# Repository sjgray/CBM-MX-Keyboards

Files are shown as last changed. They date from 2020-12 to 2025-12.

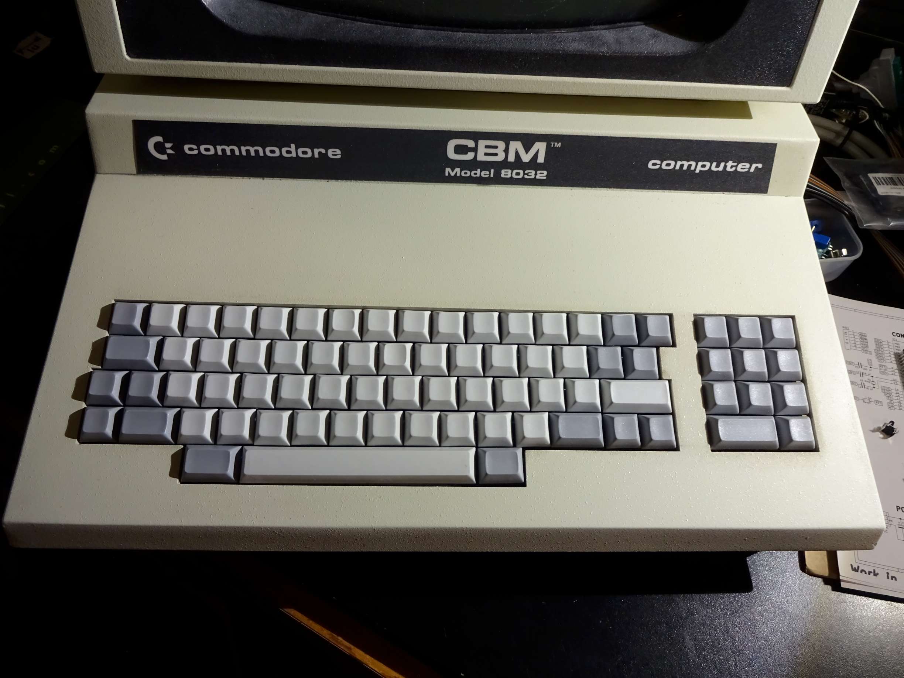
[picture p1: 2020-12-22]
PET-B/B-V1-R1/_Pics/b-v1-r1-installed.jpg

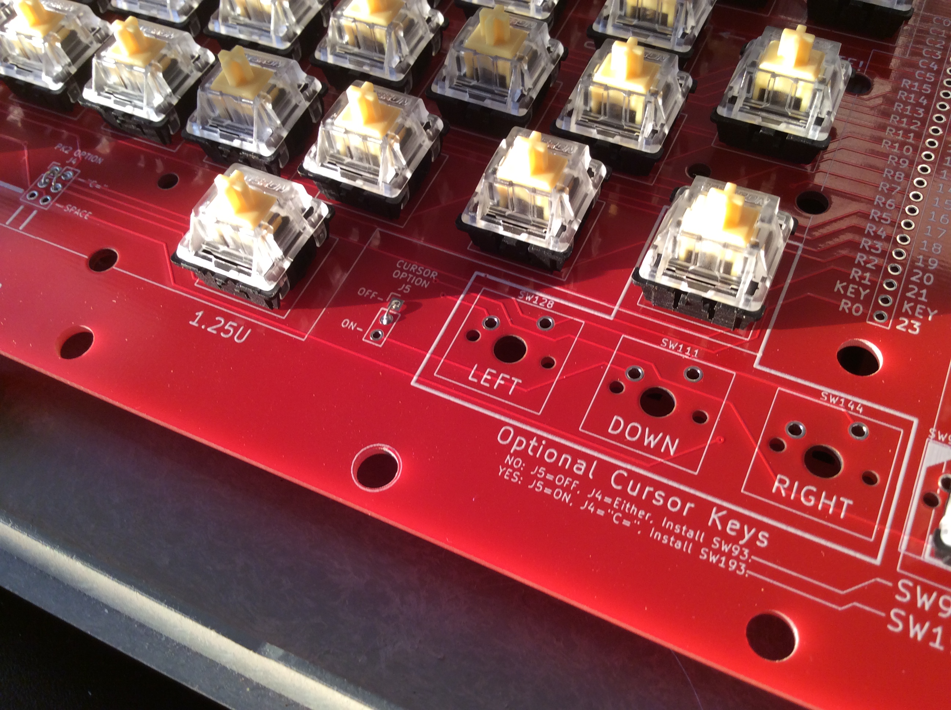
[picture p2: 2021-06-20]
CBM2/CBM2-V1-R1/_pics/cbm2-03.jpg

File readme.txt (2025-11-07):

CBM MX Keyboards Project         Steve J. Gray
========================

This is a project to create replacement keyboards for CBM Machines
using standard MX keyswitches. The first goal is to create direct
replacements that fit standard CBM cases (if possible).

KEYBOARDS
=========

Keyboards are identified by a string in the following format:

KB-Vn-Rn

where: KB is the keyboard name
       Vn is the version#. This is a unique design/layout of a specific keyboard.
       Rn is the revision#. Generally updates to a specific keyboard version.

 So, take the PET "B" keyboard. V1-R1 is the first design using pcb cutouts to allow the
keyboard to be mounted higher. When this was awkward a R2 revision was done to eliminate
the cutouts and reduce the pcb size. However this requires a 3D printed bracket to mount
it. Since both keyboards use the same switch and keycap layout both are V1. If a new
version is designed that say uses a different sized spacebar or has significant changes
then a V2 would be made. With the CLCD keyboard there are two versions. V1 has a layout
using the diamond arrow cursor keys. A V2 version instead uses an inverted-T cursor layout.

Examples:

       "B-V1-R1" is the PET/CBM "B" (Business) keyboard, Version 1, Revision 1
       "N-V1-R2" is the PET/CBM "N" (Normal/Graphic) keyboard, Version1 , Revision 2

Keyboards In Development:

	N    = PET/CBM Normal/Graphic Keyboard (4032)
	B    = PET/CBM Business Keyboard (8032, SuperPET, 8296 etc)
	CBM2 = B128, CBM128-80, 5x0, 6x0, 7x0,P500 etc
	V364 = TED series prototype with numeric pad
	CLCD = Laptop prototype
	CSX  = C128+SX64 customizable design

Planned:
	C64  = VIC-20, C64, C16 etc
	C65  = C65 with cursor keys etc
	B64  = PET "B" with C64-style layout

STICKERS
========

 Artwork for labelling keycaps is in the STICKERS folder, since that is the most likely
way to label the keys. However, stickers is not the only possibility... see webpage for
more details.

SCANS
=====

  Original keycap scans are in the SCANS folder. These are scanned with a flatbed scanner,
either the entire keyboard (stitched if required) or individual keycap top and front.

WEBPAGE
=======

For more information please visit the project webpage.
Comments and feedback are welcome!

http://www.cbmsteve.ca/mxkeyboards/index.html

HISTORY
=======

KEYBOARD    DATE        PCB?	STATUS
--------    ----        ----	------
B-V1-R1     2020-07-01  YES	Built and tested. Electrically working but requires pcb mounting hole modifications
N-V1-R1     2020-12-17  YES	Built and tested. Electrically working but does not fit in N keyboard case due to measurement error.
N/B         2021-02-10  -	Add keyboard labelling stickers for both N and B keyboards on one page.
N-V1-R2     2021-03-31  -	Add Gerbers
B-V1-R2     2023-03-21	YES	Released. Built and tested.
CSX-V1-R1   2023-09-01  YES	Testing...
CSX-V1-R1   2024-02-25  YES     Released. Built 3 configurations. Basic functionality is working but more work is needed to fully test.
V364        2024-02-25  YES     Released. Built and tested.

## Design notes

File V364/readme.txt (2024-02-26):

V364 MX Keyboard
================

This is a keyboard for the never-released V364 computer which was part of the TED series.
I designed this keyboard based on pictures of prototype machines as part of my project
to recreate the computer. The project is still in development.

I am releasing the design for people that might want a V364 keyboard for their PLUS/4 or
C16 computer which could be placed in a 3D-printed case.

The keyboard is tested and works. The numeric pad does not require any special software
to work as the keys are wired up as duplicates of existing keys in the regular PLUS/4
keyboard.

Steve

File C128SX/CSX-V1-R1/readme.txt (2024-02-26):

C128SX MX Keyboard
================== 

V1R1 Completed 2023-09-01

*** This keyboard is still in development! ***

 This is an MX keyboard with multiple possible configurations by snapping
off sections or populating keys in different locations and setting jumpers.
This design can use standard MX keyswitches, or Gateron Low-Profile
switches. I recommend Low-Profile when making C128 or SX64 keyboards.

There are 4 sections:

 1) Main section - Letters, numbers, spacebar, cursor etc.
 2) The C128 top row keys: ESC, Scroll lock, 40/80, cursor, function keys.
 3) Numeric pad.
 4) SX64 function keys (embedded in numeric pad).

The Main section has an option for an inverted-T cursor that can be enabled
by populating U1 and setting jumpers. This is handled like the C65 keyboard
where the UP and RIGHT keys are simulated by virtually pressing the SHIFT
key, and are transparent to the computer.

The C128 top row has an option to relocate the function keys to replace the
redundant cursor keys. It also has an option to use a special set of
function keys in a Plus/4 function keys style for use in C64 mode.

The NUMERIC PAD is not wired like the C128 expects, but is instead wired
into the main layout. This allows them to be used in C64 mode without any
special software. The drawback is that these keys can no longer be detected
separately from the normal number keys in C128 mode.

The SX Function Keys occupy the same space as the left side of the numeric
keypad. The MX switches must be installed in the correct locations and in
the correct orientation.

----

I have built the following configurations:
	- SX64 standard layout.
 	- C128 standard layout.
        - C64 with Plus/4-style function keys on top.

The configurations above are partially working:
	- General layout and matrix are ok.
	- Snap-off sections are ok.
	- Numeric pad works on C128 and C64.

- Not Tested:
	- Locking keys.
	- Inverted-T.
	- SX64 DB25 alignment.
	- Mounting hole alignment.

- The first revision is made available for those that need a BASIC
  replacement keyboard and do not need shift-lock or other locking
  keys.

- You can send the GERBERS to JLCPCB but they will need so adjustment
  and extra charges for the additional slots (about $7 extra per 5 boards).

- Fixes for next release:
	- Fix SX64 alignment hole position (move right)
	- Fix SX64 and C128 mounting holes
	- Reduce holes in between breakaway traces from 2.0mm to 1.8mm.
	- Move top breakaway slots down for better fit with SX config
	- Add jumpers for standard SX-64 SHIFT-LOCK (bypass ATTINY circuit)
	- Investigate adding upside-down switches for TED (V364, C16) mode:
		- R-SHIFT connect as L-SHIFT
		- BACKARROW to ESC
		- UP/DOWN key seems to have no function
		- Check other badly located keys

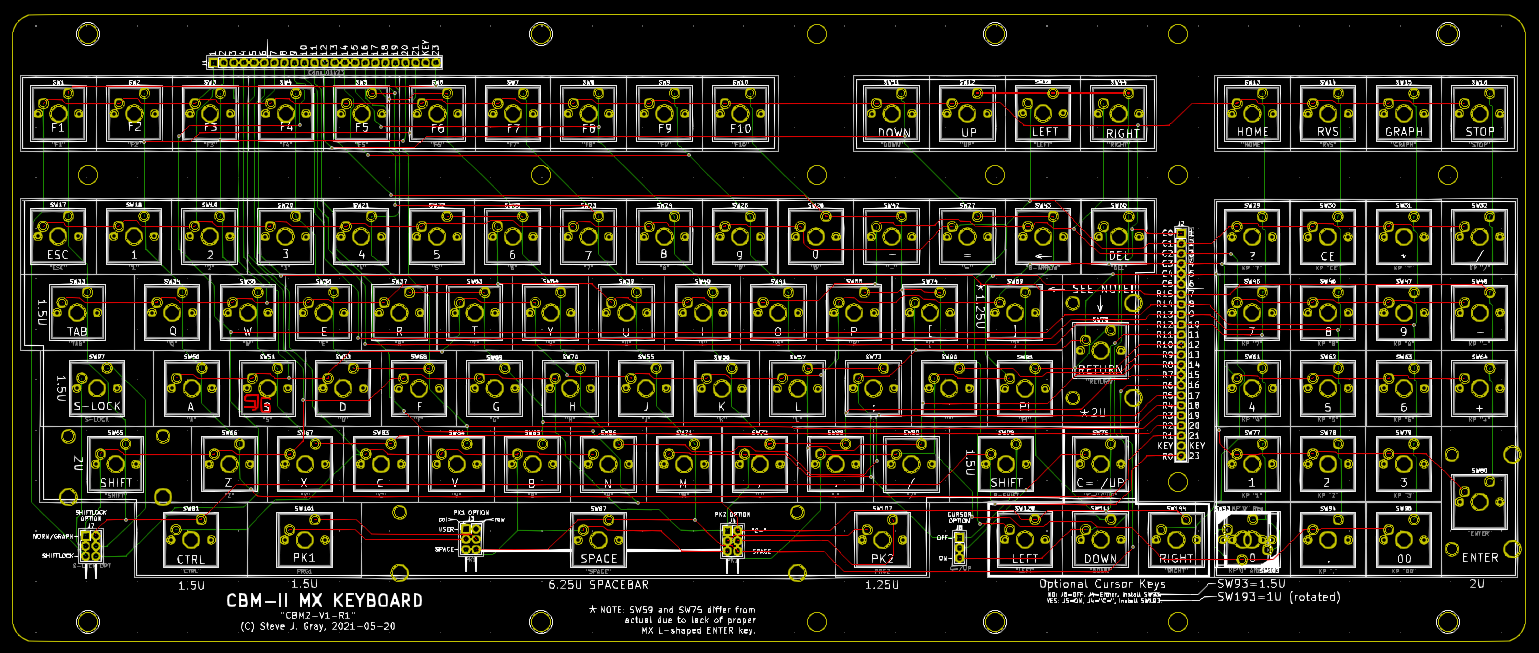
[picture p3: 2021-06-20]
CBM2/CBM2-V1-R1/_pics/pcb.png

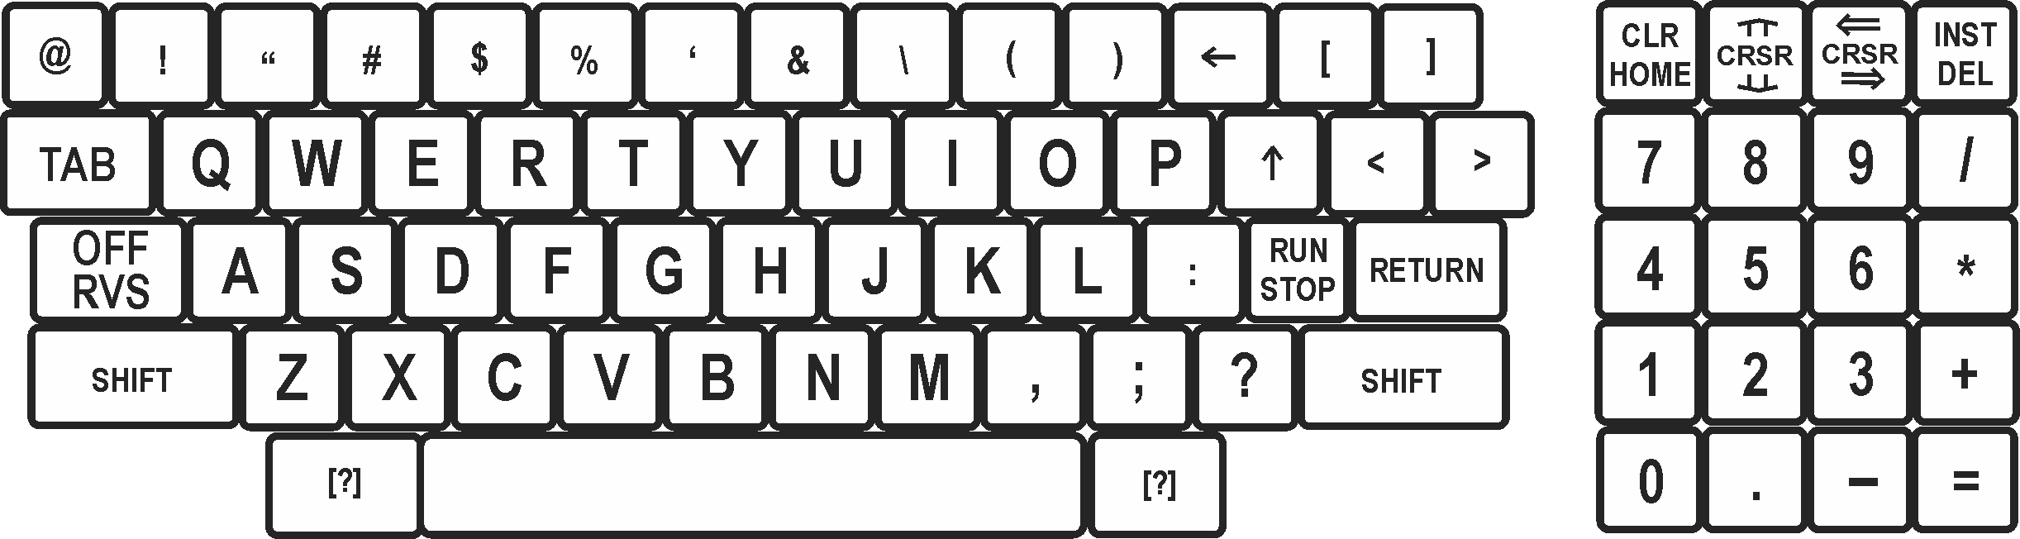
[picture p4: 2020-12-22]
PET-N/N-V1-R1/_Pics/n-v1-r1-layout.png

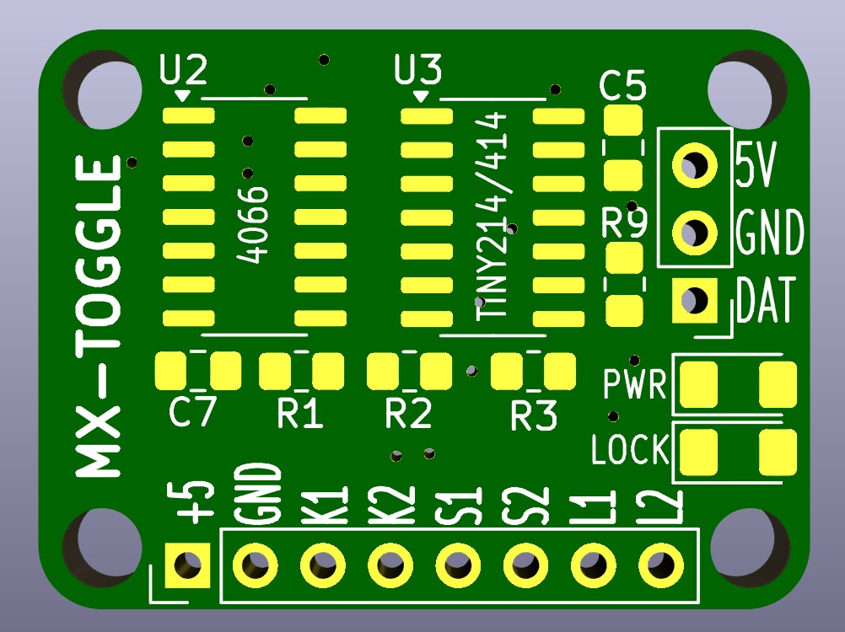
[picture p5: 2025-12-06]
MX-Toggle/pics/2025-12-04-Board-top.jpg

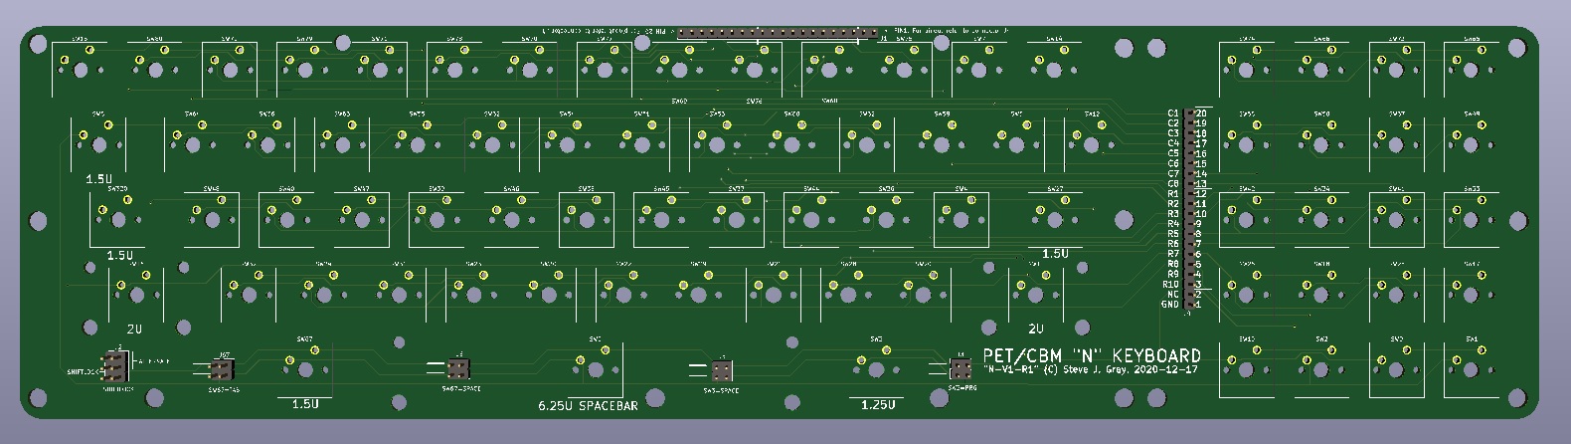
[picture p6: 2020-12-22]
PET-N/N-V1-R1/_Pics/Board-rev-2020-12-17.jpg

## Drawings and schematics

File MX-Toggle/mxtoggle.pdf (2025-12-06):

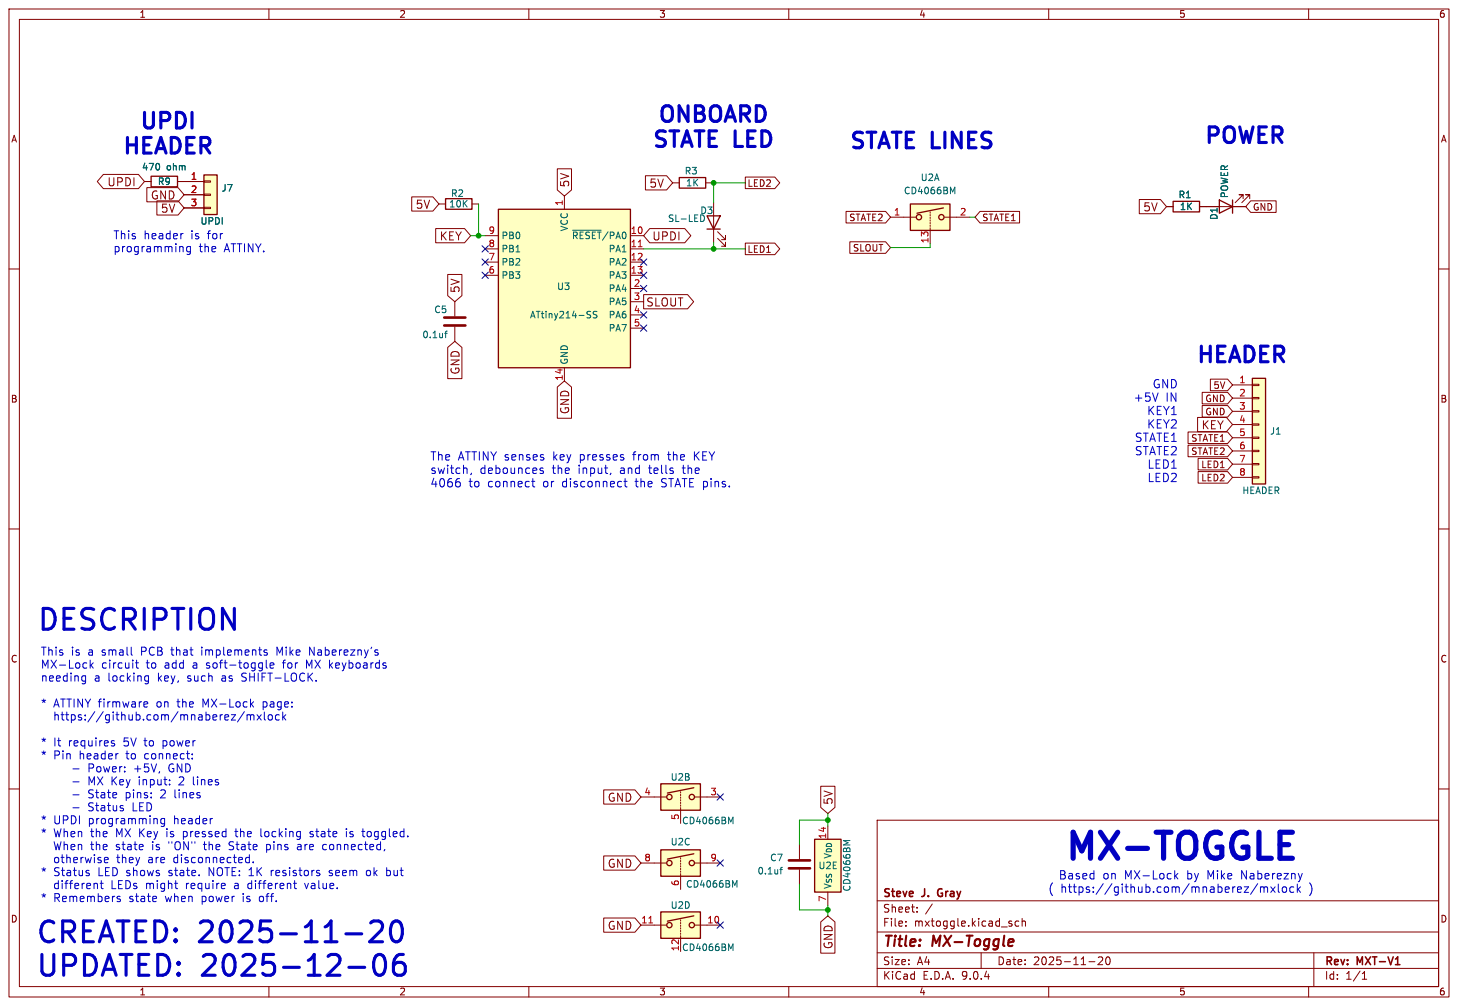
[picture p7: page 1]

This header is for

The ATTINY senses key presses from the KEY
switch, debounces the input, and tells the

https://github.com/mnaberez/mxlock

- MX Key input: 2 lines
- State pins: 2 lines
- Status LED

File: mxtoggle.kicad_sch Sheet: / Steve J. Gray

Id: 1/1 Title: MX-Toggle

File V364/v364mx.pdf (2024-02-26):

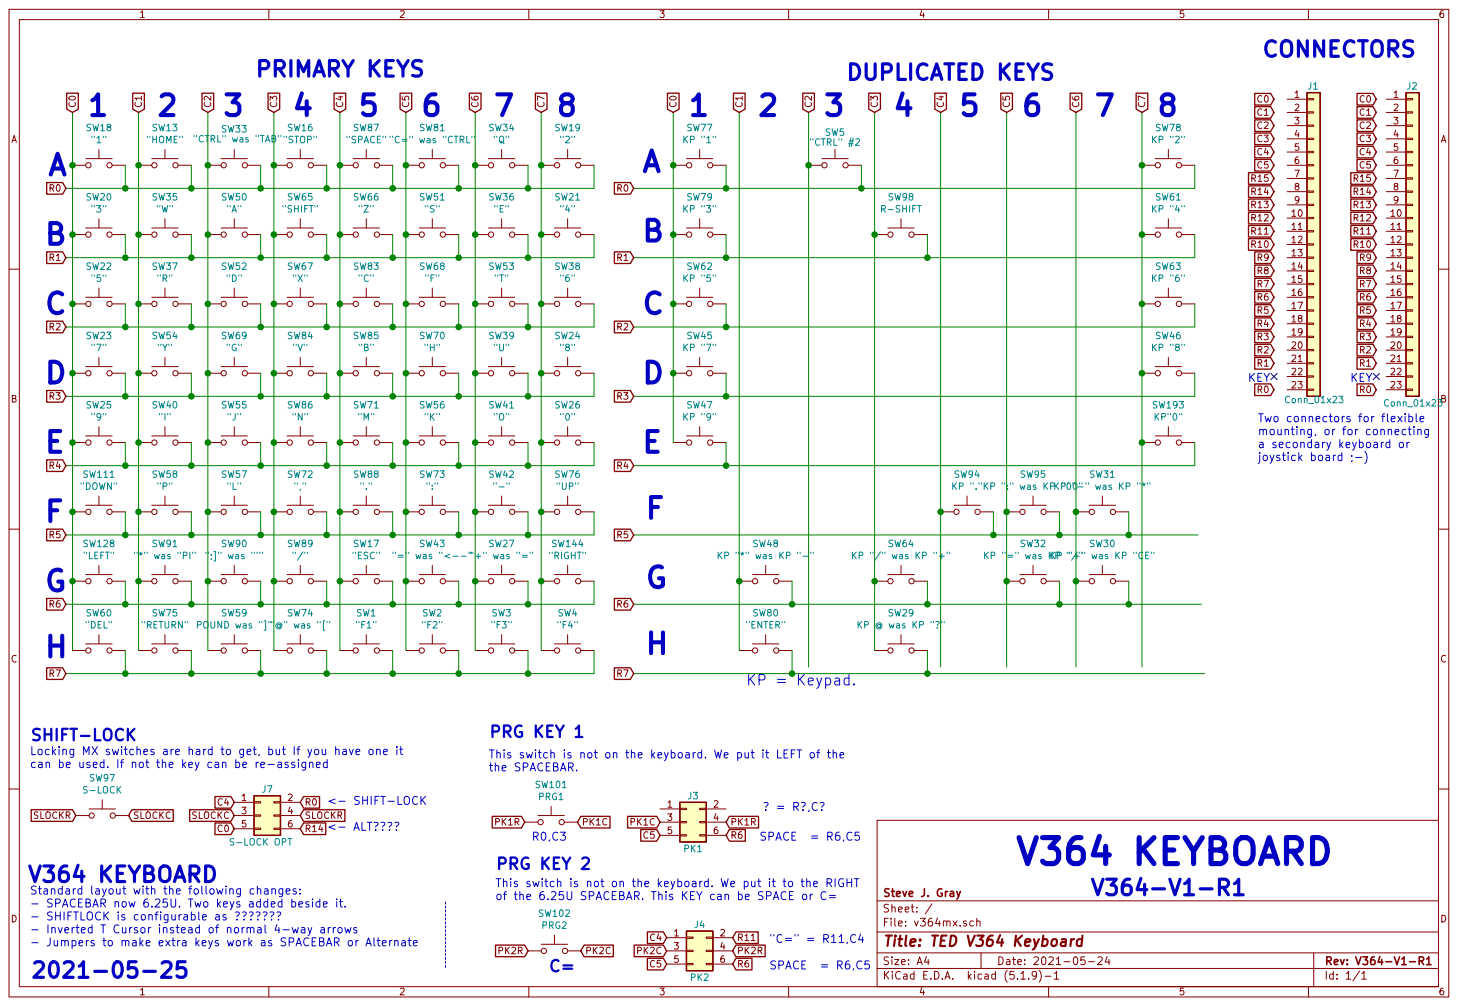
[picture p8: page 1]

Two connectors for flexible
mounting, or for connecting
a secondary keyboard or
joystick board ;-)

SHIFT-LOCK
Locking MX switches are hard to get, but If you have one it
can be used. If not the key can be re-assigned

This switch is not on the keyboard. We put it LEFT of the
the SPACEBAR.

PRG KEY 2
This switch is not on the keyboard. We put it to the RIGHT
of the 6.25U SPACEBAR. This KEY can be SPACE or C=

V364 KEYBOARD
Standard layout with the following changes:
- SPACEBAR now 6.25U. Two keys added beside it.
- SHIFTLOCK is configurable as ???????
- Inverted T Cursor instead of normal 4-way arrows
- Jumpers to make extra keys work as SPACEBAR or Alternate

File: v364mx.sch Sheet: / Steve J. Gray

Id: 1/1 Title: TED V364 Keyboard

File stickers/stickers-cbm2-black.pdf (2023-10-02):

F1 | F2 | F3 | F4 | F5 | F6 | F7 | F8 | F9 | F10 |
- | ? | CE | * @

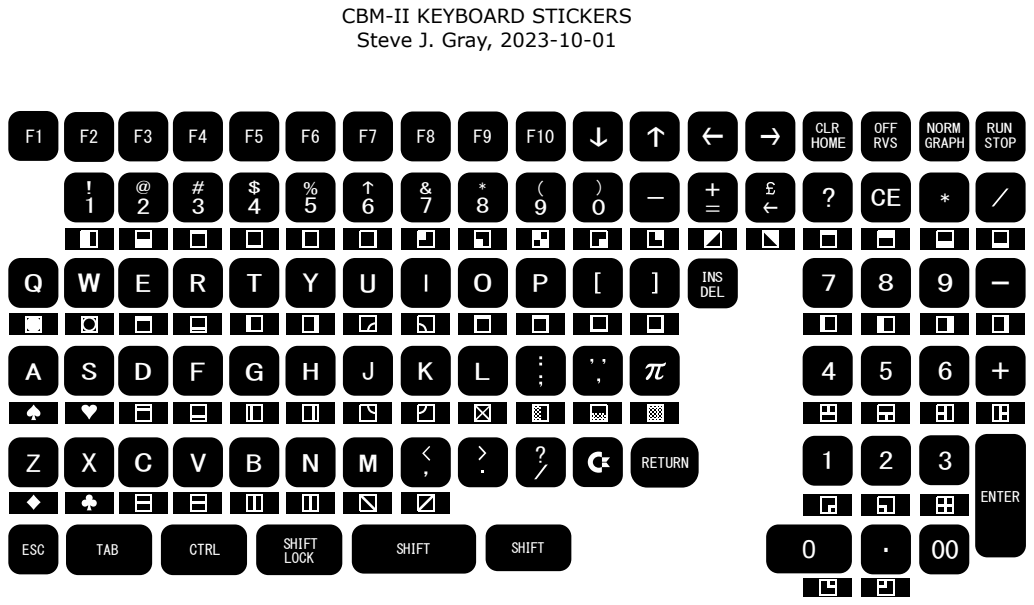
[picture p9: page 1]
RUN STOP; NORM GRAPH; OFF RVS; CLR HOME; INS; DEL; RETURN; ENTER; ESC; TAB; SHIFT SHIFT; LOCK CTRL; SHIFT

CBM-II KEYBOARD STICKERS
Steve J. Gray, 2023-10-01

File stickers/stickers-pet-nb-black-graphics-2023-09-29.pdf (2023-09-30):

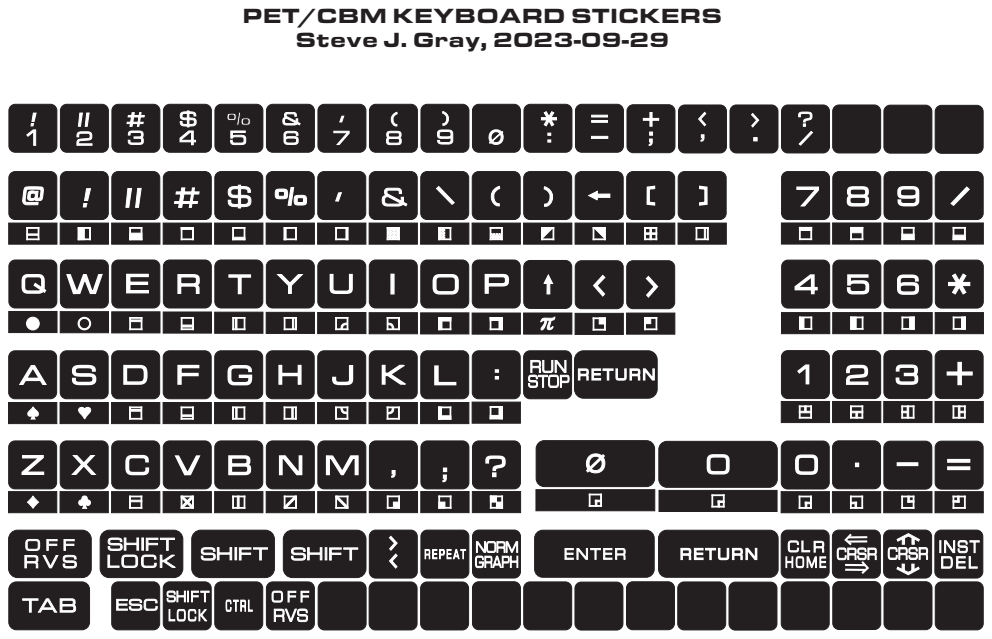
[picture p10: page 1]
ESC; C T R L SHIF T; CRSR; STOP; RUN; CRSR INST; DE L SHIFT; ENT ER; R E TURN SHIFT; LOCK; SHIFT; TAB; O F F RVS; NORM; GRAPH; R E TURN

PET/CBM KEYBOARD STICKERS
Steve J. Gray, 2023-09-29

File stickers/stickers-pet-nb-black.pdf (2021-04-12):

7

8

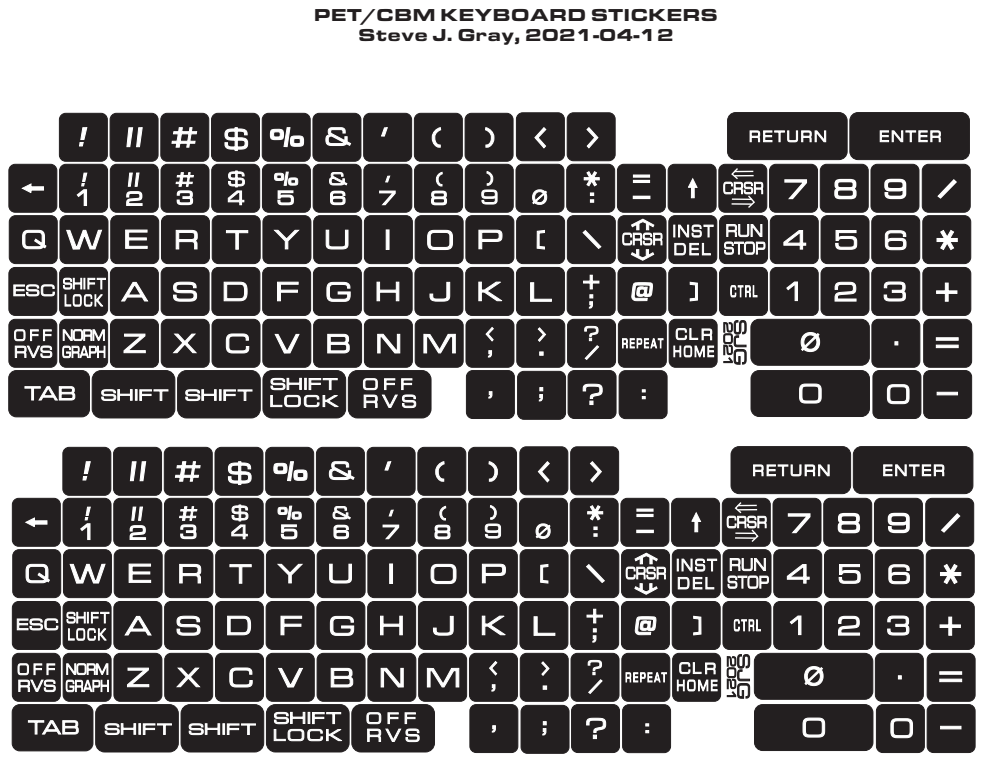
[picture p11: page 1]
ESC; RVS; SHIF T; NORM; GRAPH; SHIFT; LOCK; R E TURN; ENT ER; CRSR; STOP; RUN; INST; TAB; SJG SJG

PET/CBM KEYBOARD STICKERS
Steve J. Gray, 2021-04-12

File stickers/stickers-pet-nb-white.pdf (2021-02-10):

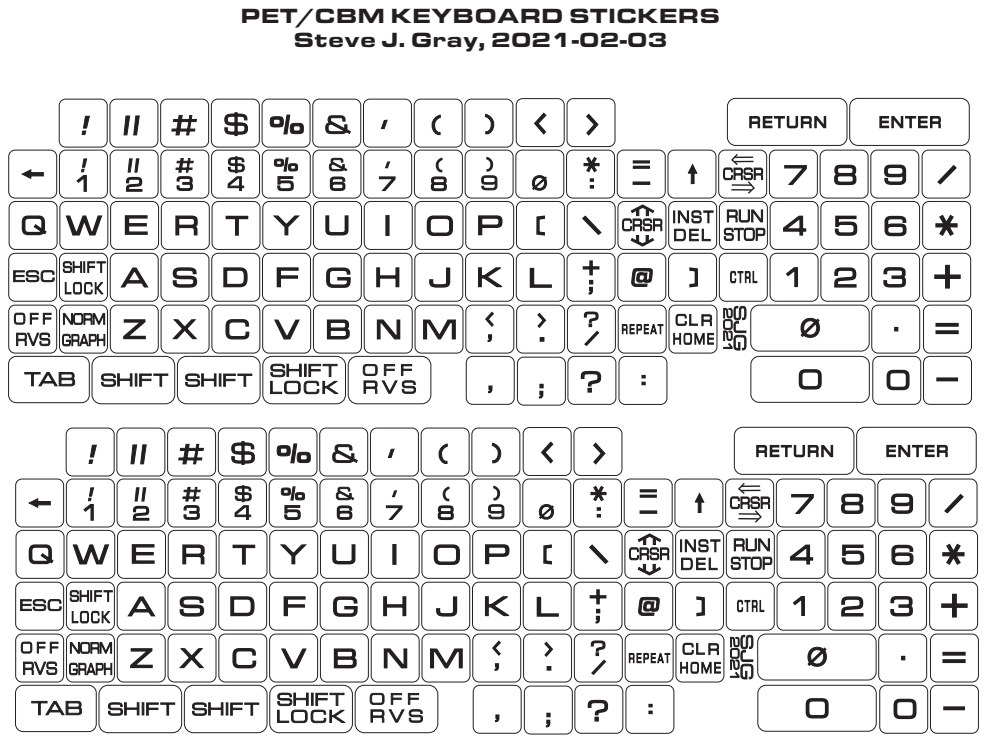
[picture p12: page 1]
ESC; RVS; SHIF T LO C K; NORM GRAPH; SHIFT; SHIFT LOCK; CRSR; STOP; RUN E R T Y U I O P; CRSR INST; R E TURN; ENT ER; TAB; 0 ²⁰²¹ SJG

PET/CBM KEYBOARD STICKERS
Steve J. Gray, 2021-02-03

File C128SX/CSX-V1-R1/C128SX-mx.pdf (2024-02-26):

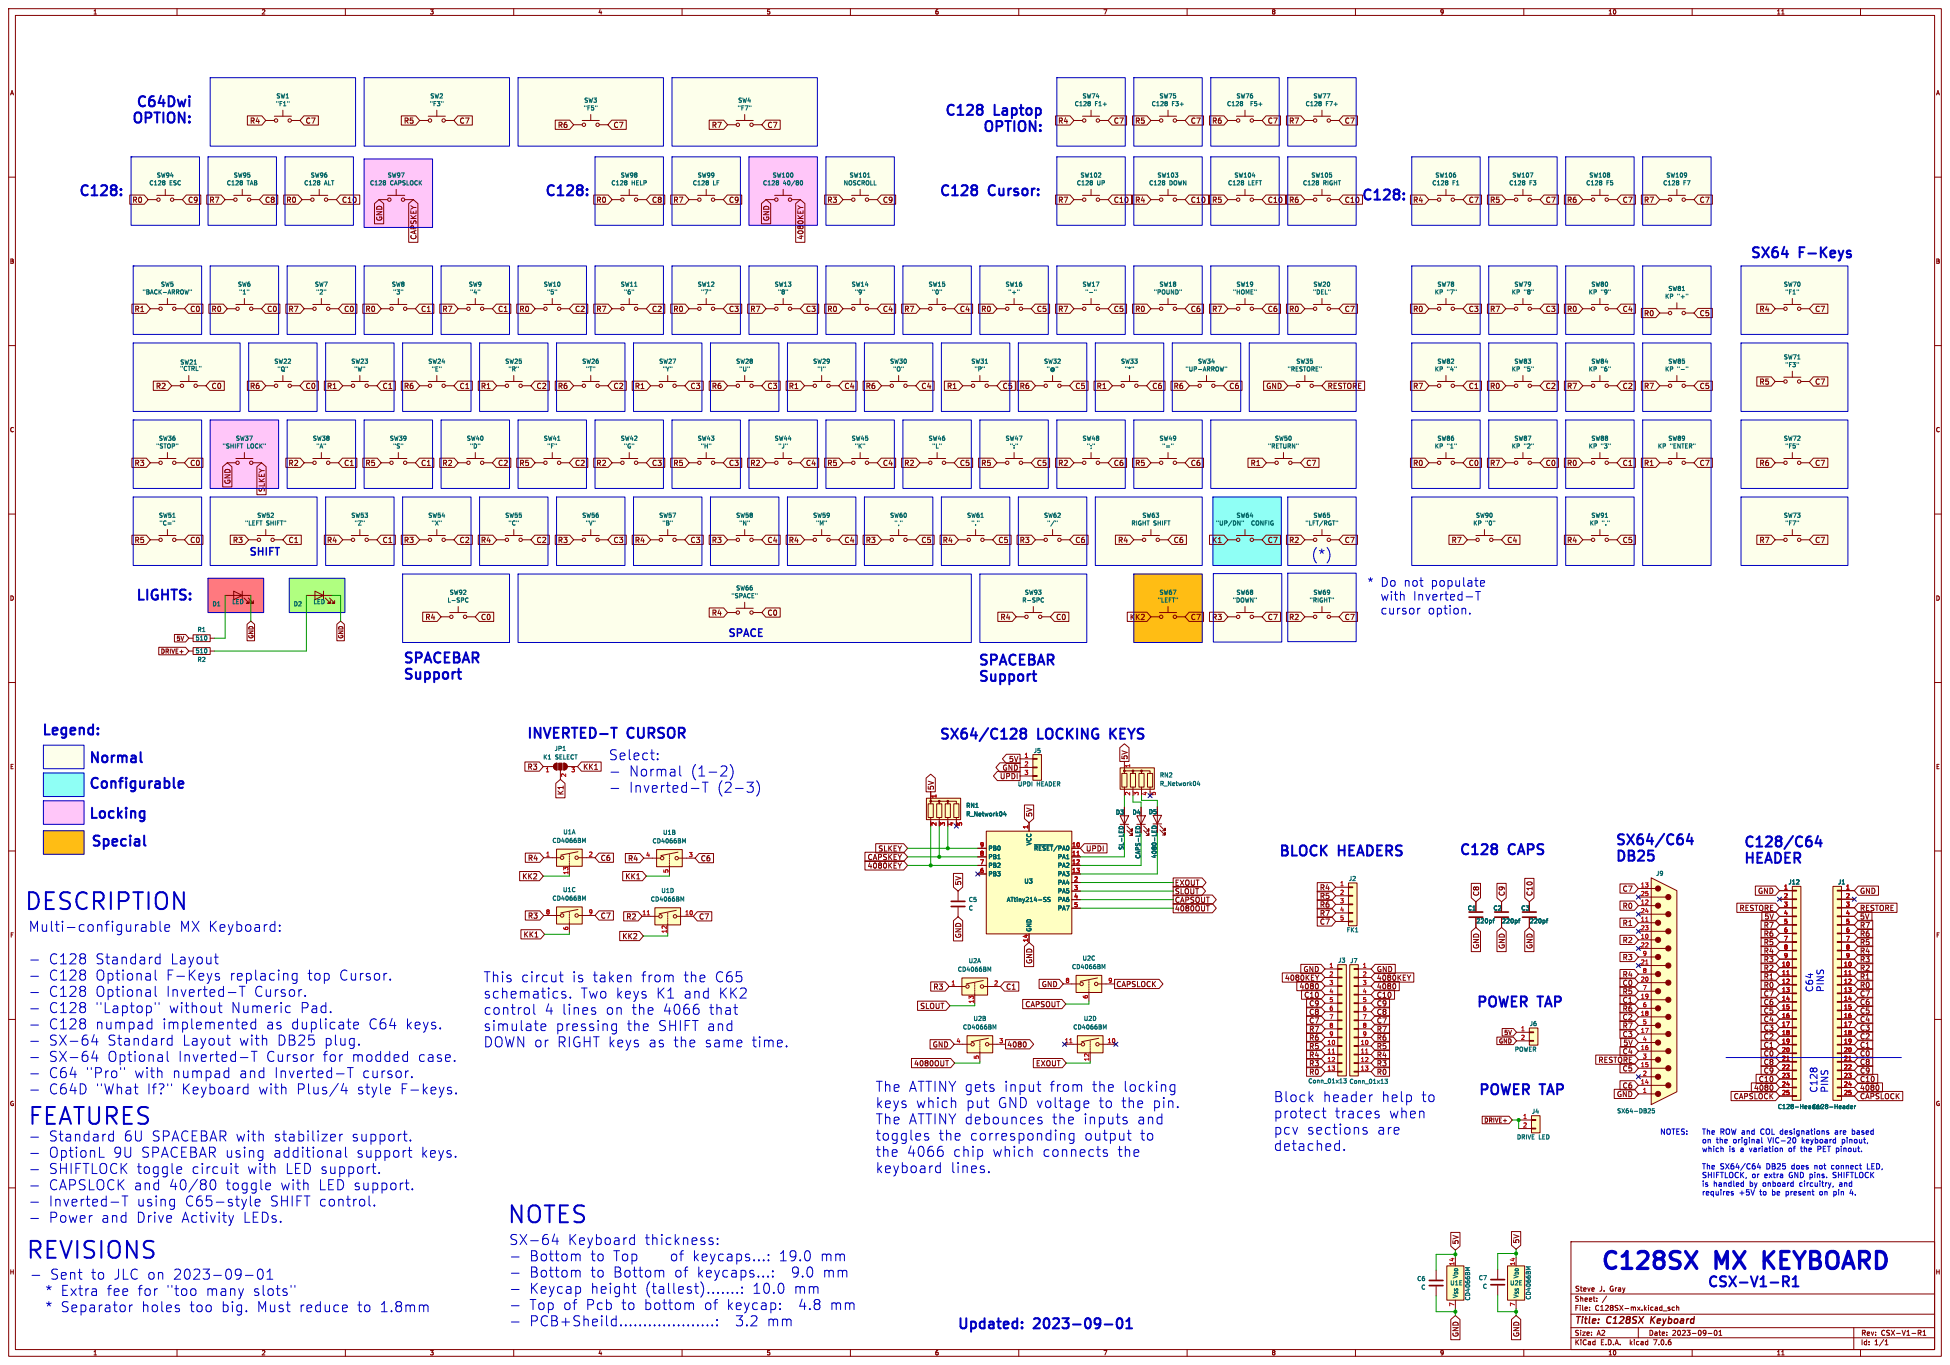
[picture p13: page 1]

This circut is taken from the C65
control 4 lines on the 4066 that
simulate pressing the SHIFT and
DOWN or RIGHT keys as the same time.

4080OUT
The ATTINY gets input from the locking
keys which put GND voltage to the pin.
The ATTINY debounces the inputs and
the 4066 chip which connects the

REVISIONS
- Sent to JLC on 2023-09-01
* Extra fee for "too many slots" * Separator holes too big. Must reduce to 1.8mm

File: C128SX-mx.kicad_sch Sheet: / Steve J. Gray

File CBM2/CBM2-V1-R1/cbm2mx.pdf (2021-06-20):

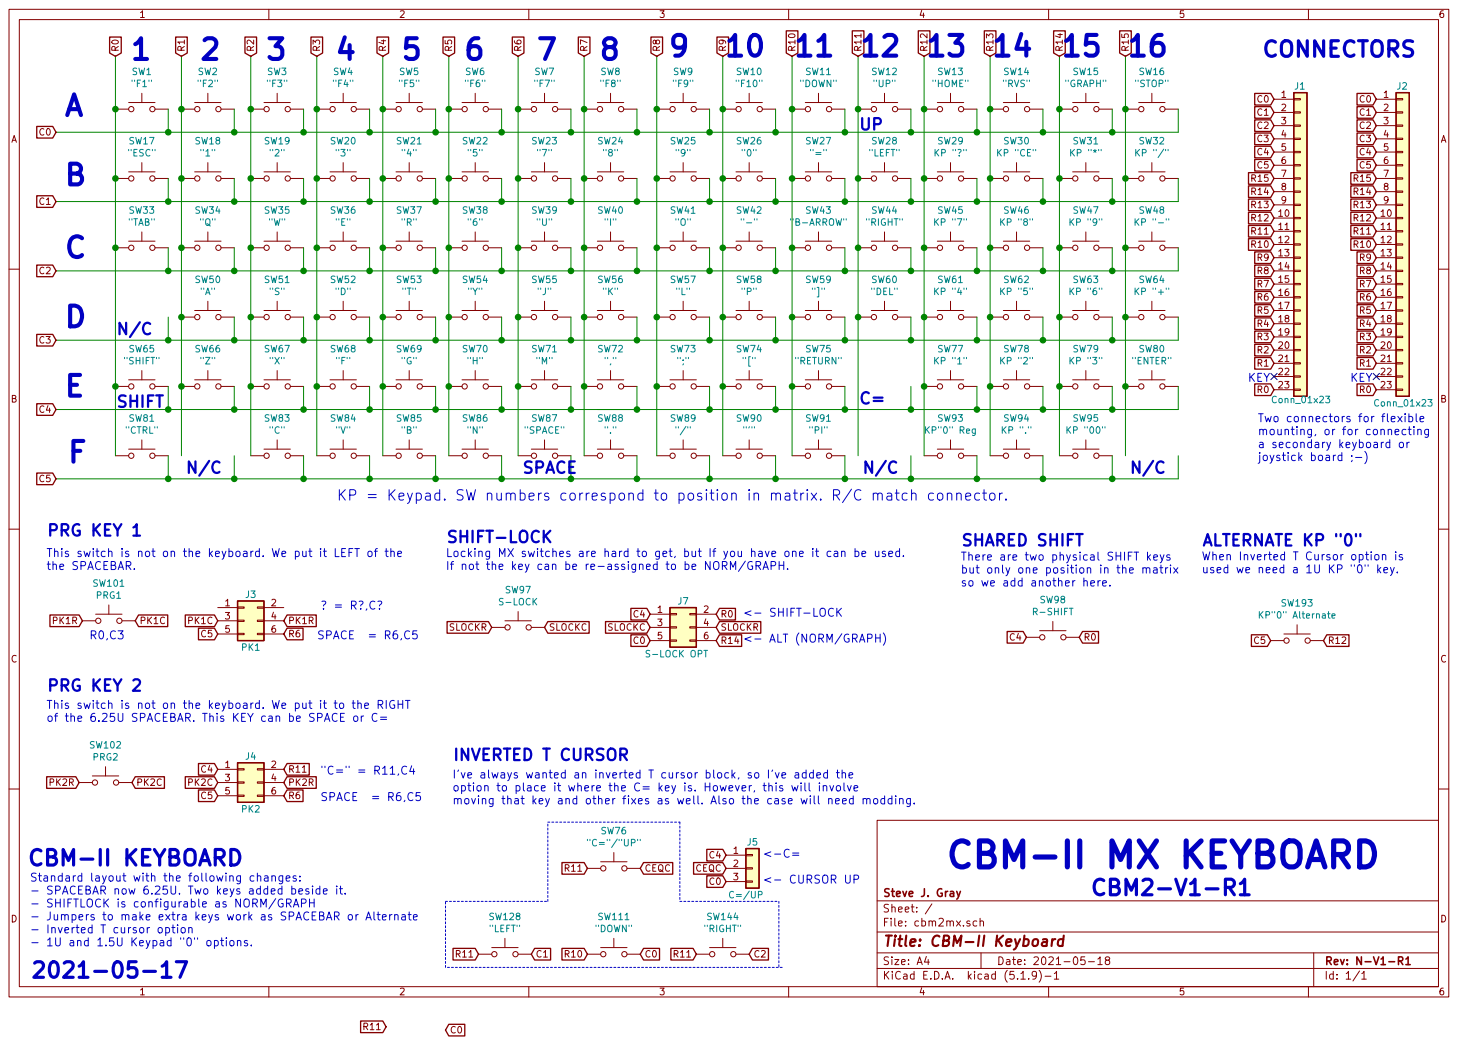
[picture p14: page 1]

Two connectors for flexible
mounting, or for connecting
a secondary keyboard or
joystick board ;-)

KP = Keypad. SW numbers correspond to position in matrix. R/C match connector.

SHIFT-LOCK
Locking MX switches are hard to get, but If you have one it can be used.
If not the key can be re-assigned to be NORM/GRAPH.

SHARED SHIFT
There are two physical SHIFT keys
but only one position in the matrix

ALTERNATE KP "0"
When Inverted T Cursor option is
used we need a 1U KP "0" key.

This switch is not on the keyboard. We put it LEFT of the
the SPACEBAR.

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

INVERTED T CURSOR
I've always wanted an inverted T cursor block, so I've added the
option to place it where the C= key is. However, this will involve
moving that key and other fixes as well. Also the case will need modding.

CBM-II MX KEYBOARD

Standard layout with the following changes:
- SPACEBAR now 6.25U. Two keys added beside it.
- SHIFTLOCK is configurable as NORM/GRAPH
- Jumpers to make extra keys work as SPACEBAR or Alternate
- Inverted T cursor option
- 1U and 1.5U Keypad "0" options.

File: cbm2mx.sch Sheet: / Steve J. Gray

Id: 1/1 Title: CBM-II Keyboard

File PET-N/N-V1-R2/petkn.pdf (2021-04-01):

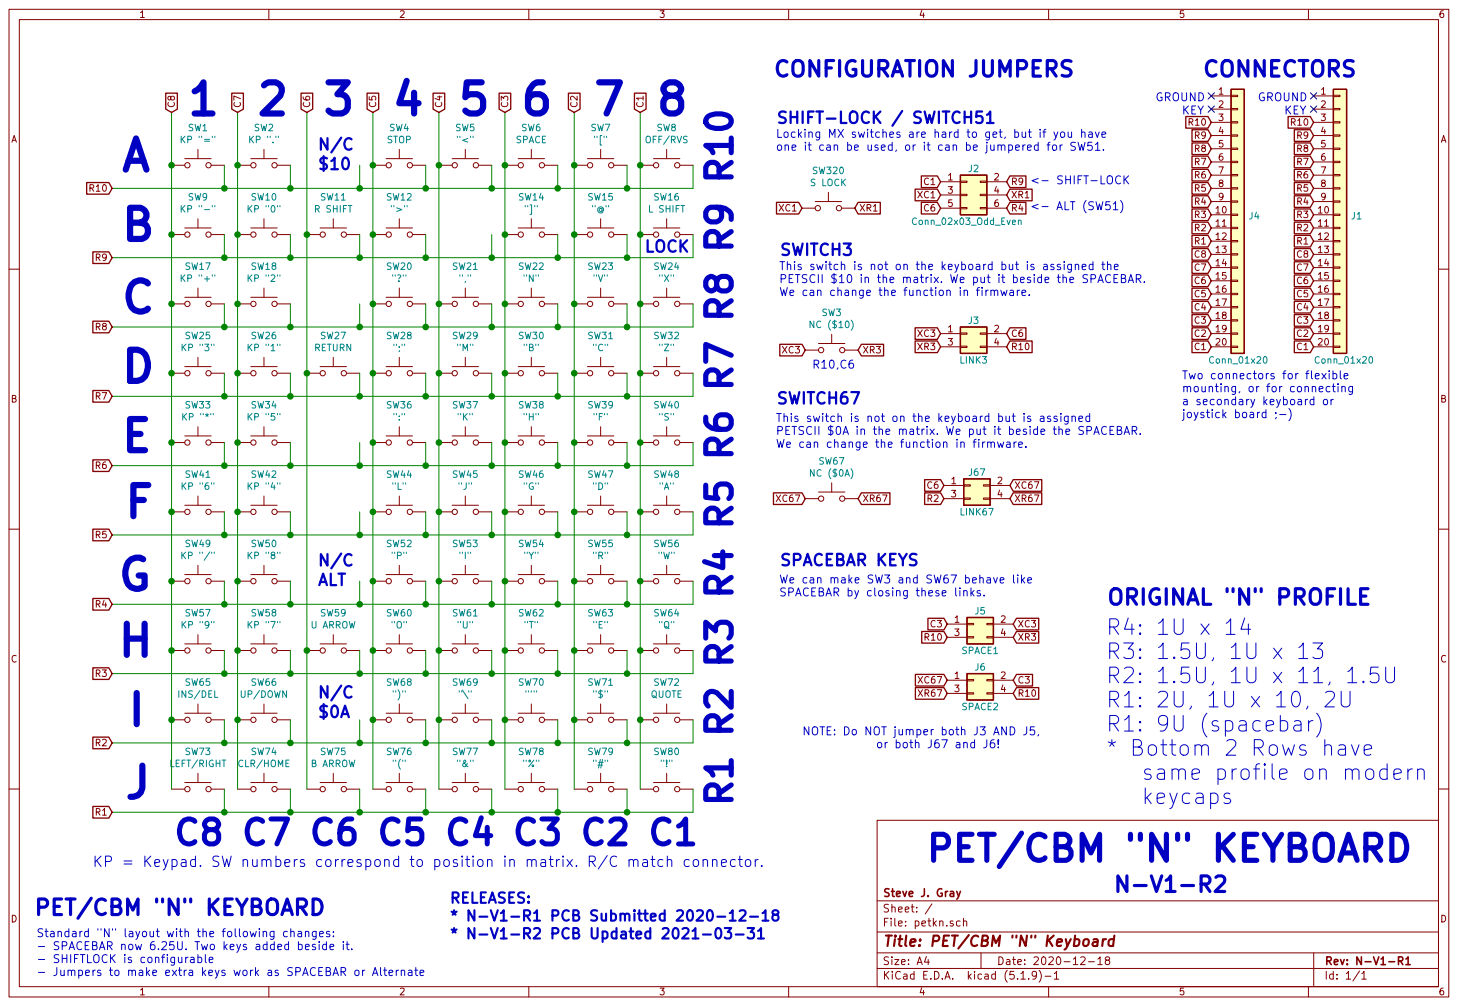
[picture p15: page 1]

SHIFT-LOCK / SWITCH51
Locking MX switches are hard to get, but if you have
one it can be used, or it can be jumpered for SW51.

SWITCH3
This switch is not on the keyboard but is assigned the
PETSCII $10 in the matrix. We put it beside the SPACEBAR.
We can change the function in firmware.

SWITCH67
This switch is not on the keyboard but is assigned
PETSCII $0A in the matrix. We put it beside the SPACEBAR.

Two connectors for flexible
mounting, or for connecting
a secondary keyboard or
joystick board ;-)

SPACEBAR KEYS
We can make SW3 and SW67 behave like
SPACEBAR by closing these links.

SW60 "O" SW59 U ARROW

NOTE: Do NOT jumper both J3 AND J5,
or both J67 and J6!

LEFT/RIGHT

KP = Keypad. SW numbers correspond to position in matrix. R/C match connector.
PET/CBM "N" KEYBOARD
Standard "N" layout with the following changes:
- SPACEBAR now 6.25U. Two keys added beside it.
- SHIFTLOCK is configurable
- Jumpers to make extra keys work as SPACEBAR or Alternate

File: petkn.sch Sheet: / Steve J. Gray

Id: 1/1 Title: PET/CBM "N" Keyboard

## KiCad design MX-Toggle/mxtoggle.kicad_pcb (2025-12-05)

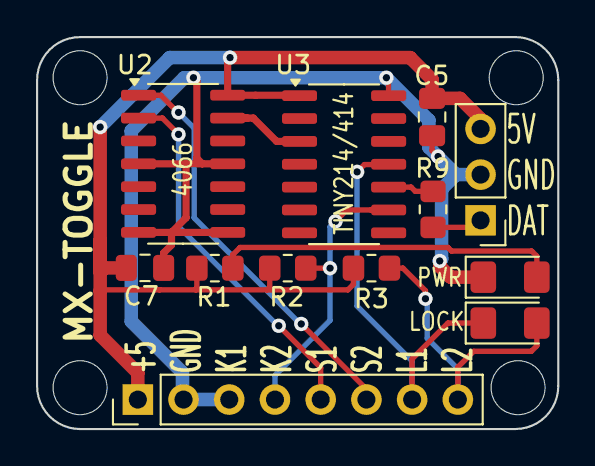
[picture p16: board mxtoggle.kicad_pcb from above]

Board: 2 copper layers, 29.0 x 21.8 mm, 12 parts (0 on the bottom side), 11 nets.

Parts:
C5, C7: 0.1uf; C_0805_2012Metric_Pad1.18x1.45mm_HandSolder
D1: POWER; D_1206_3216Metric_Pad1.42x1.75mm_HandSolder
D3: SL-LED; D_1206_3216Metric_Pad1.42x1.75mm_HandSolder
J1: HEADER; PinHeader_1x08_P2.54mm_Vertical
J7: UPDI; PinHeader_1x03_P2.54mm_Vertical
R1: 330; R_0805_2012Metric_Pad1.20x1.40mm_HandSolder
R2, R3: R; R_0805_2012Metric_Pad1.20x1.40mm_HandSolder
R9: 470 ohm; R_0805_2012Metric_Pad1.20x1.40mm_HandSolder
U2: CD4066BM; SO-14_3.9x8.65mm_P1.27mm
U3: ATtiny214-SS; SOIC-14_3.9x8.7mm_P1.27mm

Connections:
5V: C5.1, C7.1, J1.1, J7.3, R1.1, R2.1, R3.1, U2.14 (V_{DD}), U3.1 (VCC)
GND: C5.2, C7.2, D1.1 (K), J1.2, J1.3, J7.2, U2.4, U2.7 (V_{SS}), U2.8, U2.11, U3.14 (GND)
KEY: J1.4, R2.2, U3.9 (PB0)
LED1: D3.1 (K), J1.7, U3.11 (PA1)
LED2: D3.2 (A), J1.8, R3.2
unnamed: D1.2 (A), R1.2
unnamed: J7.1, R9.2
SLOUT: U2.13, U3.3 (PA5)
STATE1: J1.5, U2.2
STATE2: J1.6, U2.1
UPDI: R9.1, U3.10 (~RESET/PA0)

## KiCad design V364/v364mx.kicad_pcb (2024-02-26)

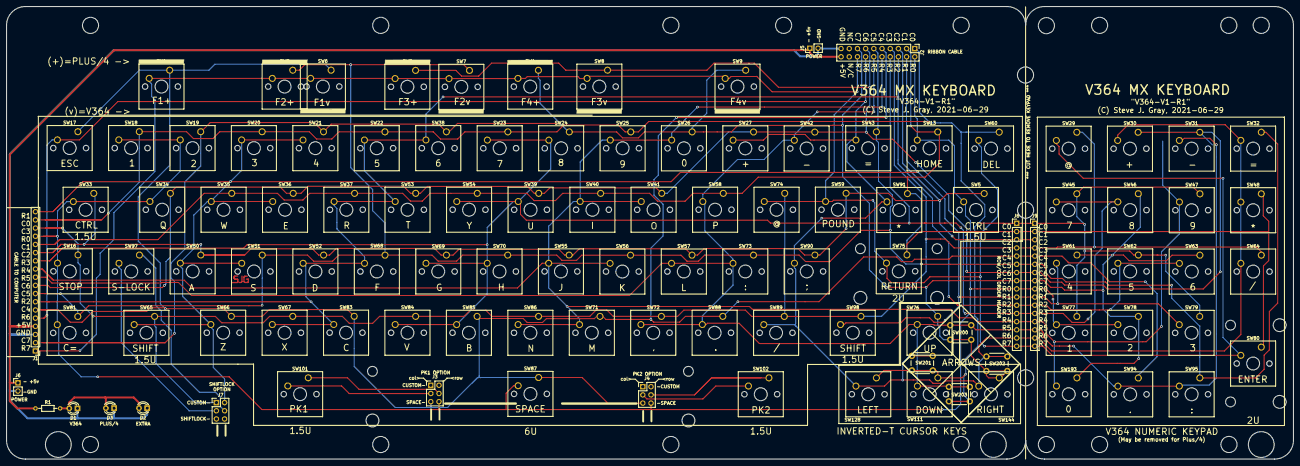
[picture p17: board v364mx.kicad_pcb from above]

Board: 2 copper layers, 399.1 x 140.3 mm, 109 parts (0 on the bottom side), 25 nets.

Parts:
D1, D2, D3: LED; LED_D3.0mm
J1: MAIN; PinHeader_1x18_P2.54mm_Vertical
J2: RIBBON CONNECTOR; PinHeader_2x10_P2.54mm_Vertical
J3: PK1; PinHeader_2x03_P2.54mm_Vertical
J4: PK2; PinHeader_2x03_P2.54mm_Vertical
J5, J6: POWER; PinHeader_1x02_P2.54mm_Vertical
J7: S-LOCK OPT; PinHeader_2x03_P2.54mm_Vertical
J8: KEYPAD1; PinHeader_1x16_P2.54mm_Vertical
J9: KEYPAD2; PinHeader_1x16_P2.54mm_Vertical
R1: 510; R_Axial_DIN0204_L3.6mm_D1.6mm_P7.62mm_Horizontal
SW1: "F1+"; SW_Cherry_MX_1.00u_PCB
SW2: "F2+"; SW_Cherry_MX_1.00u_PCB
SW3: "F3+"; SW_Cherry_MX_1.00u_PCB
SW4: "F4+"; SW_Cherry_MX_1.00u_PCB
SW5: "CTRL" #2; SW_Cherry_MX_1.50u_PCB
SW6: "F1v"; SW_Cherry_MX_1.00u_PCB
SW7: "F2v"; SW_Cherry_MX_1.00u_PCB
SW8: "F3v"; SW_Cherry_MX_1.00u_PCB
SW9: "F4v"; SW_Cherry_MX_1.00u_PCB
SW13: "HOME"; SW_Cherry_MX_1.00u_PCB
SW16: "STOP"; SW_Cherry_MX_1.00u_PCB
SW17: "ESC"; SW_Cherry_MX_1.00u_PCB
SW18: "1"; SW_Cherry_MX_1.00u_PCB
SW19: "2"; SW_Cherry_MX_1.00u_PCB
SW20: "3"; SW_Cherry_MX_1.00u_PCB
SW21: "4"; SW_Cherry_MX_1.00u_PCB
SW22: "5"; SW_Cherry_MX_1.00u_PCB
SW23: "7"; SW_Cherry_MX_1.00u_PCB
SW24: "8"; SW_Cherry_MX_1.00u_PCB
SW25: "9"; SW_Cherry_MX_1.00u_PCB
SW26: "0"; SW_Cherry_MX_1.00u_PCB
SW27: "+"; SW_Cherry_MX_1.00u_PCB
SW29: KP "@"; SW_Cherry_MX_1.00u_PCB
SW30: KP "+"; SW_Cherry_MX_1.00u_PCB
SW31: KP "-" was KP "*"; SW_Cherry_MX_1.00u_PCB
SW32: KP "="; SW_Cherry_MX_1.00u_PCB
SW33: "CTRL"; SW_Cherry_MX_1.50u_PCB
SW34: "Q"; SW_Cherry_MX_1.00u_PCB
SW35: "W"; SW_Cherry_MX_1.00u_PCB
SW36: "E"; SW_Cherry_MX_1.00u_PCB
SW37: "R"; SW_Cherry_MX_1.00u_PCB
SW38: "6"; SW_Cherry_MX_1.00u_PCB
SW39: "U"; SW_Cherry_MX_1.00u_PCB
SW40: "I"; SW_Cherry_MX_1.00u_PCB
SW41: "O"; SW_Cherry_MX_1.00u_PCB
SW42: "-"; SW_Cherry_MX_1.00u_PCB
SW43: "="; SW_Cherry_MX_1.00u_PCB
SW45: KP "7"; SW_Cherry_MX_1.00u_PCB
SW46: KP "8"; SW_Cherry_MX_1.00u_PCB
SW47: KP "9"; SW_Cherry_MX_1.00u_PCB
SW48: KP "*"; SW_Cherry_MX_1.00u_PCB
SW50: "A"; SW_Cherry_MX_1.00u_PCB
SW51: "S"; SW_Cherry_MX_1.00u_PCB
SW52: "D"; SW_Cherry_MX_1.00u_PCB
SW53: "T"; SW_Cherry_MX_1.00u_PCB
SW54: "Y"; SW_Cherry_MX_1.00u_PCB
SW55: "J"; SW_Cherry_MX_1.00u_PCB
SW56: "K"; SW_Cherry_MX_1.00u_PCB
SW57: "L"; SW_Cherry_MX_1.00u_PCB
SW58: "P"; SW_Cherry_MX_1.00u_PCB
SW59: POUND; SW_Cherry_MX_1.00u_PCB
SW60: "DEL"; SW_Cherry_MX_1.00u_PCB
SW61: KP "4"; SW_Cherry_MX_1.00u_PCB
SW62: KP "5"; SW_Cherry_MX_1.00u_PCB
SW63: KP "6"; SW_Cherry_MX_1.00u_PCB
SW64: KP "/"; SW_Cherry_MX_1.00u_PCB
SW65: "SHIFT"; SW_Cherry_MX_1.50u_PCB
SW66: "Z"; SW_Cherry_MX_1.00u_PCB
SW67: "X"; SW_Cherry_MX_1.00u_PCB
SW68: "F"; SW_Cherry_MX_1.00u_PCB
SW69: "G"; SW_Cherry_MX_1.00u_PCB
SW70: "H"; SW_Cherry_MX_1.00u_PCB
SW71: "M"; SW_Cherry_MX_1.00u_PCB
SW72: ","; SW_Cherry_MX_1.00u_PCB
SW73: ":"; SW_Cherry_MX_1.00u_PCB
SW74: "@"; SW_Cherry_MX_1.00u_PCB
SW75: "RETURN"; SW_Cherry_MX_2.00u_PCB
SW76: "UP"; SW_Cherry_MX_1.00u_PCB
SW77: KP "1"; SW_Cherry_MX_1.00u_PCB
SW78: KP "2"; SW_Cherry_MX_1.00u_PCB
SW79: KP "3"; SW_Cherry_MX_1.00u_PCB
SW80: "ENTER"; SW_Cherry_MX_2.00u_Vertical_PCB
SW81: "C="; SW_Cherry_MX_1.00u_PCB
SW83: "C"; SW_Cherry_MX_1.00u_PCB
SW84: "V"; SW_Cherry_MX_1.00u_PCB
SW85: "B"; SW_Cherry_MX_1.00u_PCB
SW86: "N"; SW_Cherry_MX_1.00u_PCB
SW87: "SPACE"; SW_Cherry_MX_6.0u_PCB
SW88: "."; SW_Cherry_MX_1.00u_PCB
SW89: "/"; SW_Cherry_MX_1.00u_PCB
SW90: ";]" was "'"; SW_Cherry_MX_1.00u_PCB
SW91: "*" was "PI"; SW_Cherry_MX_1.00u_PCB
SW94: KP "."; SW_Cherry_MX_1.00u_PCB
SW95: KP ":" was KP "00"; SW_Cherry_MX_1.00u_PCB
SW97: S-LOCK; SW_Cherry_MX_1.00u_PCB
SW98: R-SHIFT; SW_Cherry_MX_1.50u_PCB
SW101: PRG1; SW_Cherry_MX_1.50u_PCB
SW102: PRG2; SW_Cherry_MX_1.50u_PCB
SW111: "DOWN"; SW_Cherry_MX_1.00u_PCB
SW128: "LEFT"; SW_Cherry_MX_1.00u_PCB
SW144: "RIGHT"; SW_Cherry_MX_1.00u_PCB
SW193: KP"0"; SW_Cherry_MX_1.00u_PCB
SW200: UP; SW_PUSH_6mm
SW201: LEFT; SW_PUSH_6mm
SW202: RIGHT; SW_PUSH_6mm
SW203: DOWN; SW_PUSH_6mm

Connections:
5V: J1.4, J2.20, J5.1, J6.1, R1.1
C0: J1.17, J2.1, J8.1, J9.1, SW18.1, SW20.1, SW22.1, SW23.1, SW25.1, SW45.1, SW47.1, SW60.1, SW62.1, SW77.1, SW79.1, SW111.1, SW128.1, SW201.2, SW203.2
C1: J1.14, J2.3, J8.2, J9.2, SW13.1, SW35.1, SW37.1, SW40.1, SW48.1, SW54.1, SW58.1, SW75.1, SW80.1, SW91.1
C2: J1.13, J2.5, J8.3, J9.3, SW5.1, SW33.1, SW50.1, SW52.1, SW55.1, SW57.1, SW59.1, SW69.1, SW90.1
C3: J1.16, J2.7, J7.1, J8.4, J9.4, SW16.1, SW29.1, SW64.1, SW65.1, SW67.1, SW72.1, SW74.1, SW84.1, SW86.1, SW89.1, SW98.1
C4: J1.6, J2.9, J3.5, J4.5, J8.5, J9.5, SW1.1, SW6.1, SW17.1, SW66.1, SW71.1, SW83.1, SW85.1, SW87.1, SW88.1, SW94.1
C5: J1.8, J2.11, J8.6, J9.6, SW2.1, SW7.1, SW32.1, SW43.1, SW51.1, SW56.1, SW68.1, SW70.1, SW73.1, SW81.1, SW95.1
C6: J1.9, J2.13, J8.7, J9.7, SW3.1, SW8.1, SW27.1, SW30.1, SW31.1, SW34.1, SW36.1, SW39.1, SW41.1, SW42.1, SW53.1
C7: J1.2, J2.15, J8.8, J9.8, SW4.1, SW9.1, SW19.1, SW21.1, SW24.1, SW26.1, SW38.1, SW46.1, SW61.1, SW63.1, SW76.1, SW78.1, SW144.1, SW193.1, SW200.2, SW202.2
GND: D1.1, D2.1, D3.1, J1.3, J2.19, J5.2, J6.2
unnamed: D1.2, D2.2, D3.2, R1.2
PK1C: J3.3, SW101.2
PK1R: J3.4, SW101.1
PK2C: J4.3, SW102.2
PK2R: J4.4, SW102.1
R0: J1.15, J2.2, J3.6, J4.6, J8.9, J9.9, SW5.2, SW13.2, SW16.2, SW18.2, SW19.2, SW33.2, SW34.2, SW77.2, SW78.2, SW81.2, SW87.2
R1: J1.18, J2.4, J7.2, J8.10, J9.10, SW20.2, SW21.2, SW35.2, SW36.2, SW50.2, SW51.2, SW61.2, SW65.2, SW66.2, SW79.2, SW98.2
R2: J1.7, J2.6, J8.11, J9.11, SW22.2, SW37.2, SW38.2, SW52.2, SW53.2, SW62.2, SW63.2, SW67.2, SW68.2, SW83.2
R3: J1.12, J2.8, J8.12, J9.12, SW23.2, SW24.2, SW39.2, SW45.2, SW46.2, SW54.2, SW69.2, SW70.2, SW84.2, SW85.2
R4: J1.11, J2.10, J8.13, J9.13, SW25.2, SW26.2, SW40.2, SW41.2, SW47.2, SW55.2, SW56.2, SW71.2, SW86.2, SW193.2
R5: J1.10, J2.12, J8.14, J9.14, SW31.2, SW42.2, SW57.2, SW58.2, SW72.2, SW73.2, SW76.2, SW88.2, SW94.2, SW95.2, SW111.2, SW200.1, SW203.1
R6: J1.5, J2.14, J8.15, J9.15, SW17.2, SW27.2, SW30.2, SW32.2, SW43.2, SW48.2, SW64.2, SW89.2, SW90.2, SW91.2, SW128.2, SW144.2, SW201.1, SW202.1
R7: J1.1, J2.16, J8.16, J9.16, SW1.2, SW2.2, SW3.2, SW4.2, SW6.2, SW7.2, SW8.2, SW9.2, SW29.2, SW59.2, SW60.2, SW74.2, SW75.2, SW80.2
SLOCKC: J7.3, SW97.2
SLOCKR: J7.4, SW97.1

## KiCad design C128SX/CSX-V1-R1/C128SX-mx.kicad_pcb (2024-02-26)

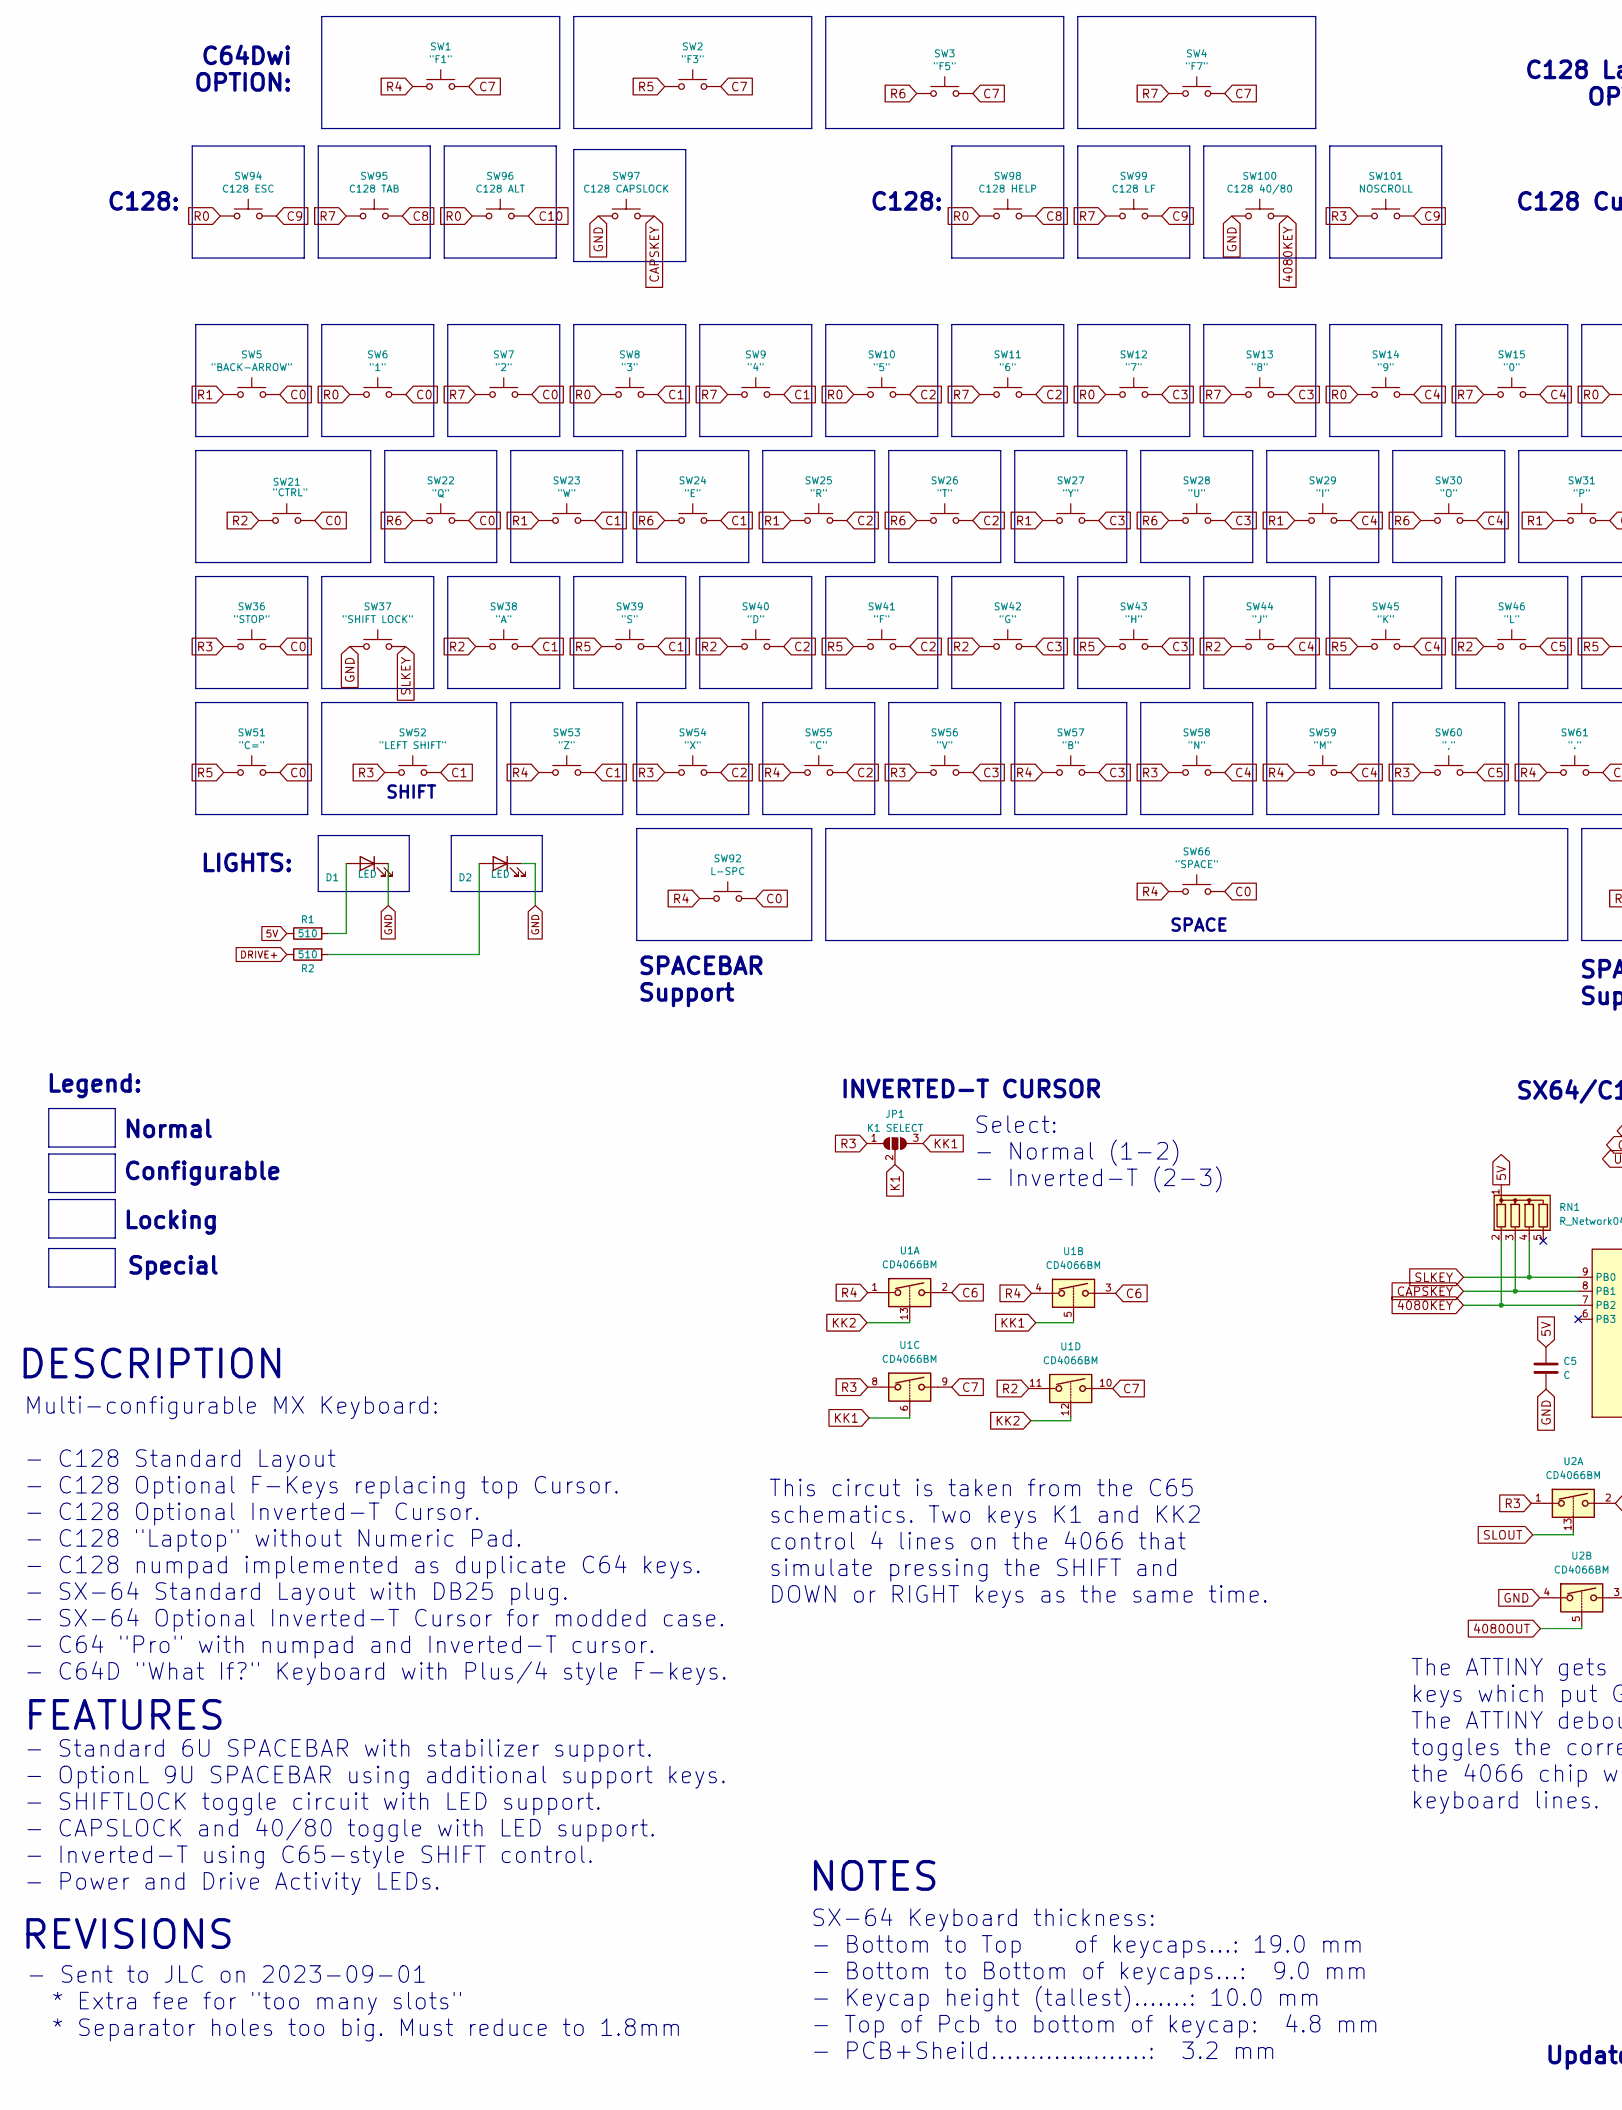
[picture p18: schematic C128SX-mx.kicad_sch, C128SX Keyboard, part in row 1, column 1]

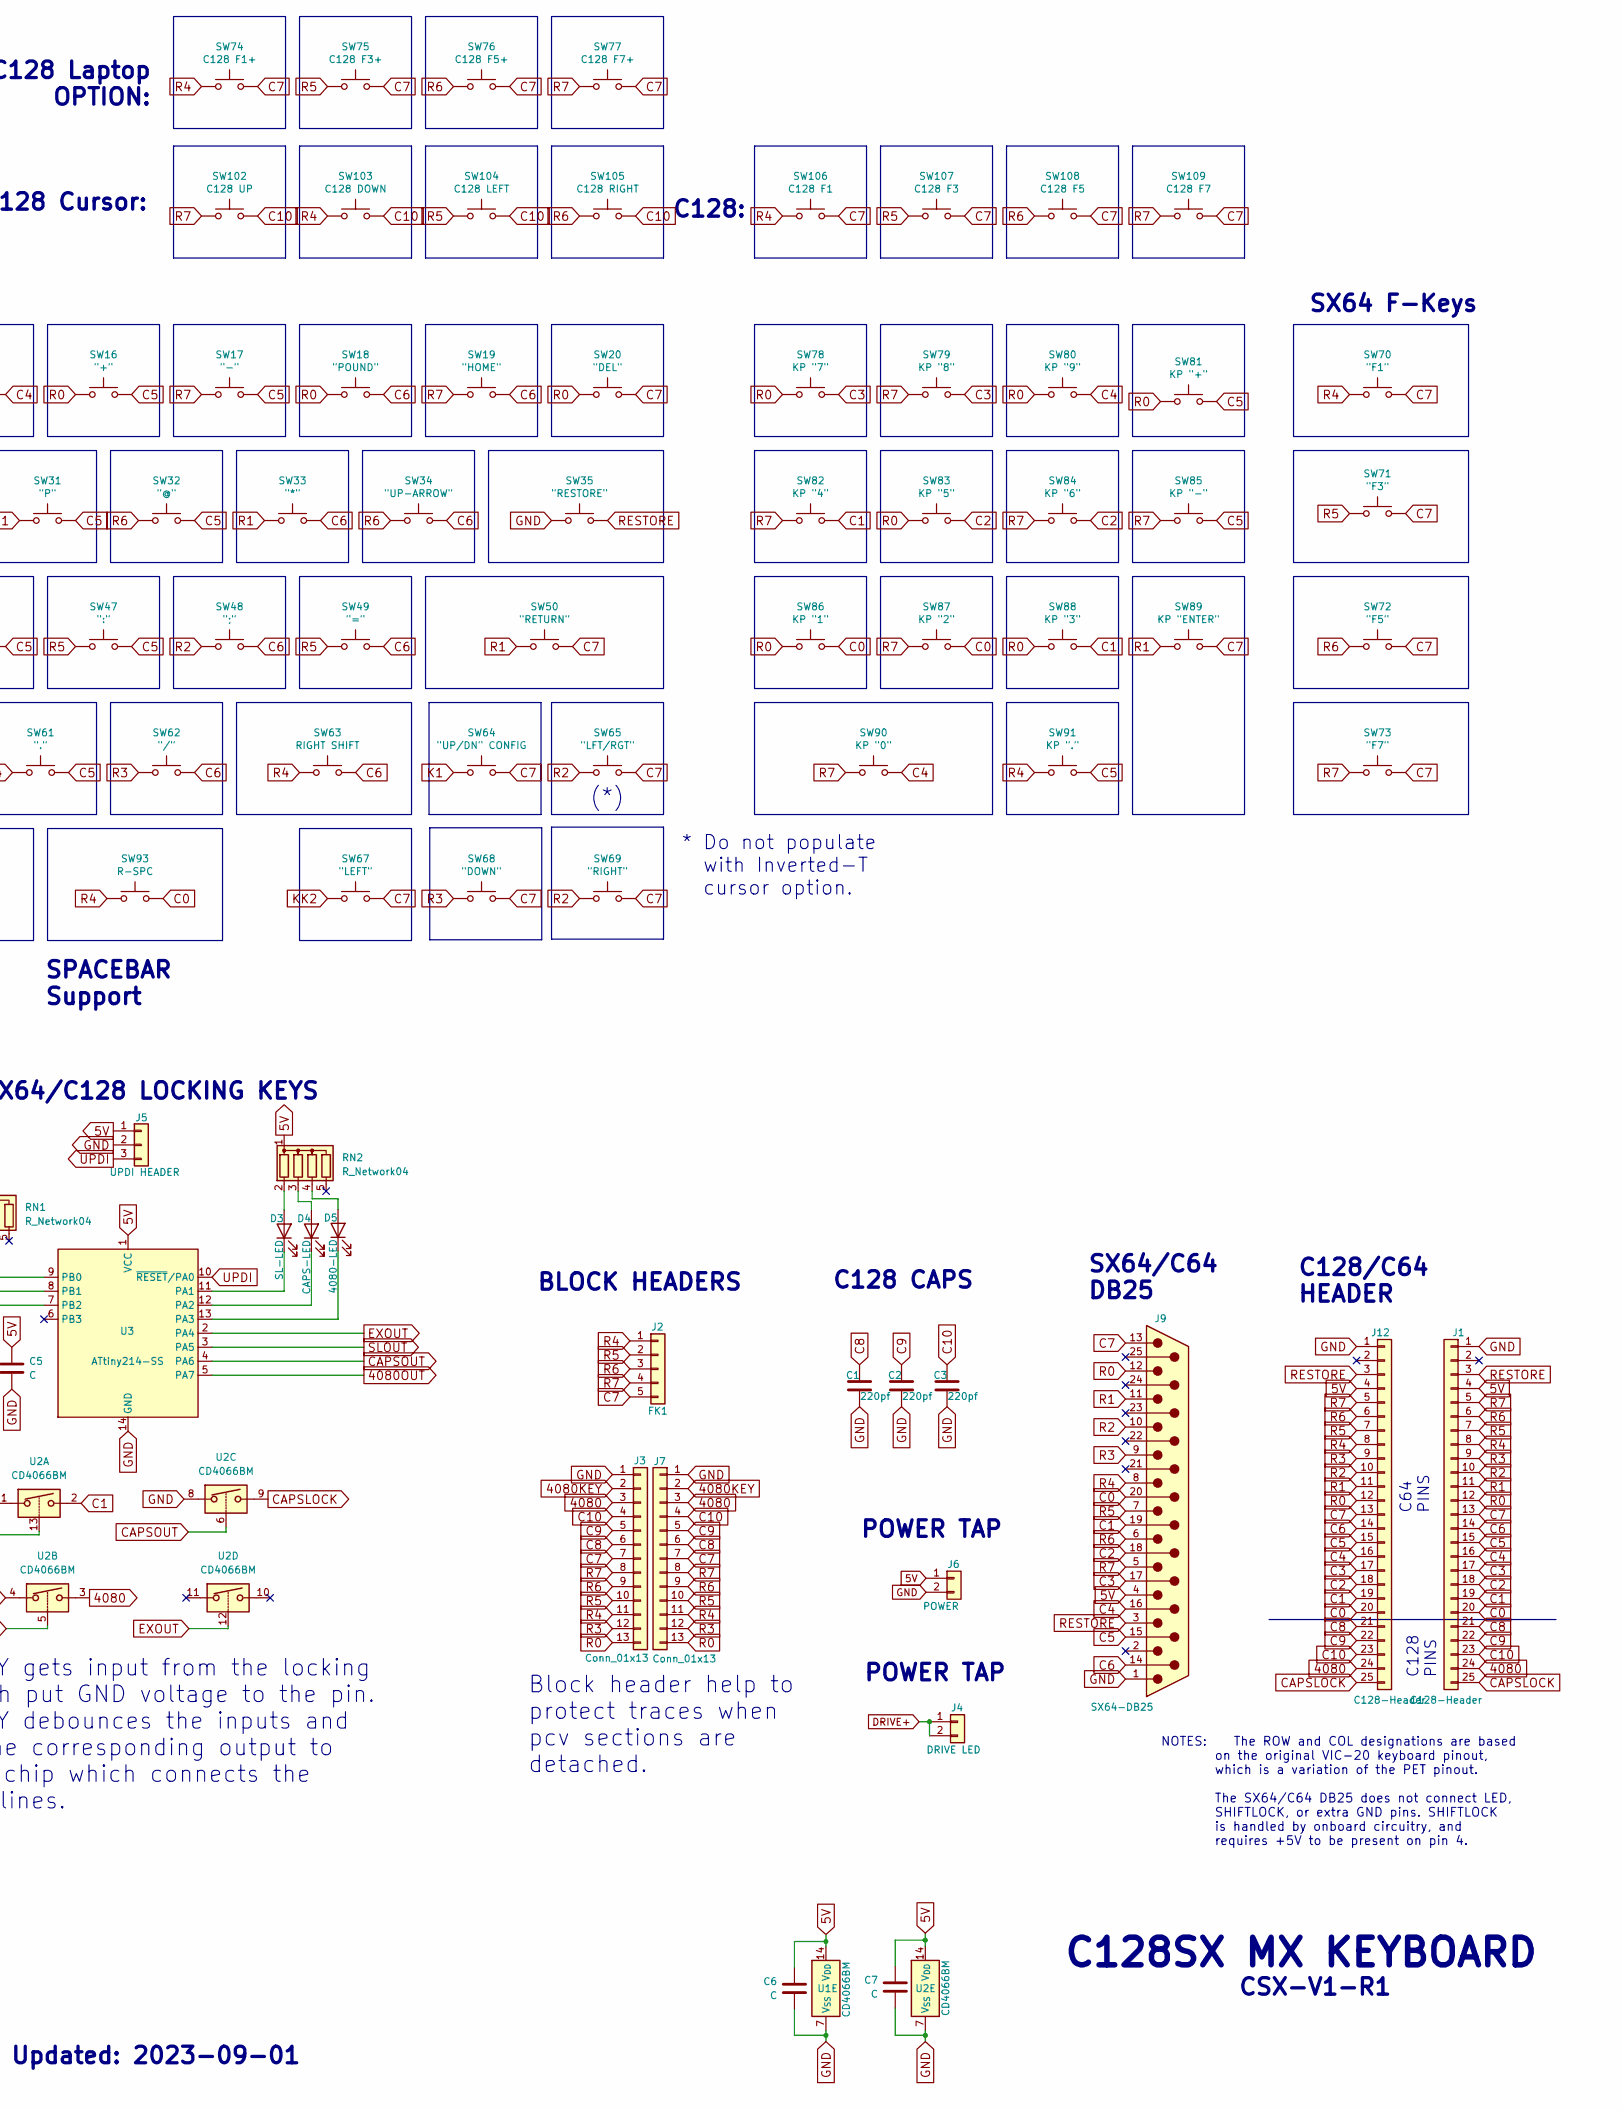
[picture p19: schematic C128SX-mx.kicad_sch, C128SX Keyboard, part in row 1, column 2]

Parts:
C1, C2, C3: 220pf; C_Disc_D4.7mm_W2.5mm_P5.00mm
C5, C6, C7: C; C_Disc_D5.0mm_W2.5mm_P5.00mm
D1, D2: LED; LED_D3.0mm
D3: SL-LED; LED_D3.0mm
D4: CAPS-LED; LED_D3.0mm
D5: 4080-LED; LED_D3.0mm
J1, J12: C128-Header; PinHeader_1x25_P2.54mm_Vertical
J2: FK1; PinHeader_1x05_P2.54mm_Vertical
J3, J7: Conn_01x13; PinHeader_1x13_P2.54mm_Vertical
J4: DRIVE LED; PinHeader_1x02_P2.54mm_Vertical
J5: UPDI HEADER; PinHeader_1x03_P2.54mm_Vertical
J6: POWER; PinHeader_1x02_P2.54mm_Vertical
J9: SX64-DB25; DSUB-25_Female_Horizontal_P2.77x2.84mm_EdgePinOffset7.70mm_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
JP1: K1 SELECT; SolderJumper-3_P1.3mm_Open_RoundedPad1.0x1.5mm_NumberLabels
R1, R2: 510; R_Axial_DIN0204_L3.6mm_D1.6mm_P7.62mm_Horizontal
RN1, RN2: R_Network04; R_Array_SIP5
SW1, SW70: "F1"; SW_Hybrid_CherryMX_GateronLP_1.00u_PCB
SW2, SW71: "F3"; SW_Hybrid_CherryMX_GateronLP_1.00u_PCB
SW3, SW72: "F5"; SW_Hybrid_CherryMX_GateronLP_1.00u_PCB
SW4, SW73: "F7"; SW_Hybrid_CherryMX_GateronLP_1.00u_PCB
SW5: "BACK-ARROW"; SW_Hybrid_CherryMX_GateronLP_1.00u_PCB
SW6: "1"; SW_Hybrid_CherryMX_GateronLP_1.00u_PCB
SW7: "2"; SW_Hybrid_CherryMX_GateronLP_1.00u_PCB
SW8: "3"; SW_Hybrid_CherryMX_GateronLP_1.00u_PCB
SW9: "4"; SW_Hybrid_CherryMX_GateronLP_1.00u_PCB
SW10: "5"; SW_Hybrid_CherryMX_GateronLP_1.00u_PCB
SW11: "6"; SW_Hybrid_CherryMX_GateronLP_1.00u_PCB
SW12: "7"; SW_Hybrid_CherryMX_GateronLP_1.00u_PCB
SW13: "8"; SW_Hybrid_CherryMX_GateronLP_1.00u_PCB
SW14: "9"; SW_Hybrid_CherryMX_GateronLP_1.00u_PCB
SW15: "0"; SW_Hybrid_CherryMX_GateronLP_1.00u_PCB
SW16: "+"; SW_Hybrid_CherryMX_GateronLP_1.00u_PCB
SW17: "-"; SW_Hybrid_CherryMX_GateronLP_1.00u_PCB
SW18: "POUND"; SW_Hybrid_CherryMX_GateronLP_1.00u_PCB
SW19: "HOME"; SW_Hybrid_CherryMX_GateronLP_1.00u_PCB
SW20: "DEL"; SW_Hybrid_CherryMX_GateronLP_1.00u_PCB
SW21: "CTRL"; SW_Hybrid_CherryMX_GateronLP_1.50u_PCB
SW22: "Q"; SW_Hybrid_CherryMX_GateronLP_1.00u_PCB
SW23: "W"; SW_Hybrid_CherryMX_GateronLP_1.00u_PCB
SW24: "E"; SW_Hybrid_CherryMX_GateronLP_1.00u_PCB
SW25: "R"; SW_Hybrid_CherryMX_GateronLP_1.00u_PCB
SW26: "T"; SW_Hybrid_CherryMX_GateronLP_1.00u_PCB
SW27: "Y"; SW_Hybrid_CherryMX_GateronLP_1.00u_PCB
SW28: "U"; SW_Hybrid_CherryMX_GateronLP_1.00u_PCB
SW29: "I"; SW_Hybrid_CherryMX_GateronLP_1.00u_PCB
SW30: "O"; SW_Hybrid_CherryMX_GateronLP_1.00u_PCB
SW31: "P"; SW_Hybrid_CherryMX_GateronLP_1.00u_PCB
SW32: "@"; SW_Hybrid_CherryMX_GateronLP_1.00u_PCB
SW33: "*"; SW_Hybrid_CherryMX_GateronLP_1.00u_PCB
SW34: "UP-ARROW"; SW_Hybrid_CherryMX_GateronLP_1.00u_PCB
SW35: "RESTORE"; SW_Hybrid_CherryMX_GateronLP_1.50u_PCB
SW36: "STOP"; SW_Hybrid_CherryMX_GateronLP_1.00u_PCB
SW37: "SHIFT LOCK"; SW_Hybrid_CherryMX_GateronLP_1.00u_PCB
SW38: "A"; SW_Hybrid_CherryMX_GateronLP_1.00u_PCB
SW39: "S"; SW_Hybrid_CherryMX_GateronLP_1.00u_PCB
SW40: "D"; SW_Hybrid_CherryMX_GateronLP_1.00u_PCB
SW41: "F"; SW_Hybrid_CherryMX_GateronLP_1.00u_PCB
SW42: "G"; SW_Hybrid_CherryMX_GateronLP_1.00u_PCB
SW43: "H"; SW_Hybrid_CherryMX_GateronLP_1.00u_PCB
SW44: "J"; SW_Hybrid_CherryMX_GateronLP_1.00u_PCB
SW45: "K"; SW_Hybrid_CherryMX_GateronLP_1.00u_PCB
SW46: "L"; SW_Hybrid_CherryMX_GateronLP_1.00u_PCB
SW47: ":"; SW_Hybrid_CherryMX_GateronLP_1.00u_PCB
SW48: ";"; SW_Hybrid_CherryMX_GateronLP_1.00u_PCB
SW49: "="; SW_Hybrid_CherryMX_GateronLP_1.00u_PCB
SW50: "RETURN"; SW_Hybrid_CherryMX_GateronLP_2.00u_PCB
SW51: "C="; SW_Hybrid_CherryMX_GateronLP_1.00u_PCB
SW52: "LEFT SHIFT"; SW_Hybrid_CherryMX_GateronLP_1.50u_PCB
SW53: "Z"; SW_Hybrid_CherryMX_GateronLP_1.00u_PCB
SW54: "X"; SW_Hybrid_CherryMX_GateronLP_1.00u_PCB
SW55: "C"; SW_Hybrid_CherryMX_GateronLP_1.00u_PCB
SW56: "V"; SW_Hybrid_CherryMX_GateronLP_1.00u_PCB
SW57: "B"; SW_Hybrid_CherryMX_GateronLP_1.00u_PCB
SW58: "N"; SW_Hybrid_CherryMX_GateronLP_1.00u_PCB
SW59: "M"; SW_Hybrid_CherryMX_GateronLP_1.00u_PCB
SW60: ","; SW_Hybrid_CherryMX_GateronLP_1.00u_PCB
SW61: "."; SW_Hybrid_CherryMX_GateronLP_1.00u_PCB
SW62: "/"; SW_Hybrid_CherryMX_GateronLP_1.00u_PCB
SW63: RIGHT SHIFT; SW_Hybrid_CherryMX_GateronLP_1.50u_PCB
SW64: "UP/DN" CONFIG; SW_Hybrid_CherryMX_GateronLP_1.00u_PCB
SW65: "LFT/RGT"; SW_Hybrid_CherryMX_GateronLP_1.00u_PCB
SW66: "SPACE"; SW_Hybrid_CherryMX_GateronLP_6.0u_Stabs_PCB
SW67: "LEFT"; SW_Hybrid_CherryMX_GateronLP_1.00u_PCB
SW68: "DOWN"; SW_Hybrid_CherryMX_GateronLP_1.00u_PCB
SW69: "RIGHT"; SW_Hybrid_CherryMX_GateronLP_1.00u_PCB
SW74: C128 F1+; SW_Hybrid_CherryMX_GateronLP_1.00u_PCB
SW75: C128 F3+; SW_Hybrid_CherryMX_GateronLP_1.00u_PCB
SW76: C128 F5+; SW_Hybrid_CherryMX_GateronLP_1.00u_PCB
SW77: C128 F7+; SW_Hybrid_CherryMX_GateronLP_1.00u_PCB
SW78: KP "7"; SW_Hybrid_CherryMX_GateronLP_1.00u_PCB
SW79: KP "8"; SW_Hybrid_CherryMX_GateronLP_1.00u_PCB
SW80: KP "9"; SW_Hybrid_CherryMX_GateronLP_1.00u_PCB
SW81: KP "+"; SW_Hybrid_CherryMX_GateronLP_1.00u_PCB
SW82: KP "4"; SW_Hybrid_CherryMX_GateronLP_1.00u_PCB
SW83: KP "5"; SW_Hybrid_CherryMX_GateronLP_1.00u_PCB
SW84: KP "6"; SW_Hybrid_CherryMX_GateronLP_1.00u_PCB
SW85: KP "-"; SW_Hybrid_CherryMX_GateronLP_1.00u_PCB
SW86: KP "1"; SW_Hybrid_CherryMX_GateronLP_1.00u_PCB
SW87: KP "2"; SW_Hybrid_CherryMX_GateronLP_1.00u_PCB
SW88: KP "3"; SW_Hybrid_CherryMX_GateronLP_1.00u_PCB
SW89: KP "ENTER"; SW_Hybrid_CherryMX_GateronLP_2.00u_Vertical_PCB
SW90: KP "0"; SW_Hybrid_CherryMX_GateronLP_2.00u_NoStab_PCB
SW91: KP "."; SW_Hybrid_CherryMX_GateronLP_1.00u_PCB
SW92: L-SPC; SW_Hybrid_CherryMX_GateronLP_1.50u_PCB
SW93: R-SPC; SW_Hybrid_CherryMX_GateronLP_1.50u_PCB
SW94: C128 ESC; SW_Hybrid_CherryMX_GateronLP_1.00u_PCB
SW95: C128 TAB; SW_Hybrid_CherryMX_GateronLP_1.00u_PCB
SW96: C128 ALT; SW_Hybrid_CherryMX_GateronLP_1.00u_PCB
SW97: C128 CAPSLOCK; SW_Hybrid_CherryMX_GateronLP_1.00u_PCB
SW98: C128 HELP; SW_Hybrid_CherryMX_GateronLP_1.00u_PCB
SW99: C128 LF; SW_Hybrid_CherryMX_GateronLP_1.00u_PCB
SW100: C128 40/80; SW_Hybrid_CherryMX_GateronLP_1.00u_PCB
SW101: NOSCROLL; SW_Hybrid_CherryMX_GateronLP_1.00u_PCB
SW102: C128 UP; SW_Hybrid_CherryMX_GateronLP_1.00u_PCB
SW103: C128 DOWN; SW_Hybrid_CherryMX_GateronLP_1.00u_PCB
SW104: C128 LEFT; SW_Hybrid_CherryMX_GateronLP_1.00u_PCB
SW105: C128 RIGHT; SW_Hybrid_CherryMX_GateronLP_1.00u_PCB
SW106: C128 F1; SW_Hybrid_CherryMX_GateronLP_1.00u_PCB
SW107: C128 F3; SW_Hybrid_CherryMX_GateronLP_1.00u_PCB
SW108: C128 F5; SW_Hybrid_CherryMX_GateronLP_1.00u_PCB
SW109: C128 F7; SW_Hybrid_CherryMX_GateronLP_1.00u_PCB
U1, U2: CD4066BM; SO-14_3.9x8.65mm_P1.27mm
U3: ATtiny214-SS; SOIC-14_3.9x8.7mm_P1.27mm

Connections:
5V: C5.1, C6.1, C7.1, J1.4, J5.1, J6.1, J9.4, J12.4, R1.1, RN1.1 (common), RN2.1 (common), U1.14 (V_{DD}), U2.14 (V_{DD}), U3.1 (VCC)
4080: J1.24, J3.3, J7.3, J12.24, U2.3
4080KEY: J3.2, J7.2, RN1.2 (R1), SW100.2, U3.7 (PB2)
4080OUT: U2.5, U3.5 (PA7)
C0: J1.20, J9.20, J12.20, SW5.2, SW6.2, SW7.2, SW21.2, SW22.2, SW36.2, SW51.2, SW66.2, SW86.2, SW87.2, SW92.2, SW93.2
C1: J1.19, J9.19, J12.19, SW8.2, SW9.2, SW23.2, SW24.2, SW38.2, SW39.2, SW52.2, SW53.2, SW82.2, SW88.2, U2.2
C2: J1.18, J9.18, J12.18, SW10.2, SW11.2, SW25.2, SW26.2, SW40.2, SW41.2, SW54.2, SW55.2, SW83.2, SW84.2
C3: J1.17, J9.17, J12.17, SW12.2, SW13.2, SW27.2, SW28.2, SW42.2, SW43.2, SW56.2, SW57.2, SW78.2, SW79.2
C4: J1.16, J9.16, J12.16, SW14.2, SW15.2, SW29.2, SW30.2, SW44.2, SW45.2, SW58.2, SW59.2, SW80.2, SW90.2
C5: J1.15, J9.15, J12.15, SW16.2, SW17.2, SW31.2, SW32.2, SW46.2, SW47.2, SW60.2, SW61.2, SW81.2, SW85.2, SW91.2
C6: J1.14, J9.14, J12.14, SW18.2, SW19.2, SW33.2, SW34.2, SW48.2, SW49.2, SW62.2, SW63.2, U1.2, U1.3
C7: J1.13, J2.5, J3.7, J7.7, J9.13, J12.13, SW1.2, SW2.2, SW3.2, SW4.2, SW20.2, SW50.2, SW64.2, SW65.2, SW67.2, SW68.2, SW69.2, SW70.2, SW71.2, SW72.2, SW73.2, SW74.2, SW75.2, SW76.2, SW77.2, SW89.2, SW106.2, SW107.2, SW108.2, SW109.2, U1.9, U1.10
C8: C1.1, J1.21, J3.6, J7.6, J12.21, SW95.2, SW98.2
C9: C2.1, J1.22, J3.5, J7.5, J12.22, SW94.2, SW99.2, SW101.2
C10: C3.1, J1.23, J3.4, J7.4, J12.23, SW96.2, SW102.2, SW103.2, SW104.2, SW105.2
CAPSKEY: RN1.3 (R2), SW97.2, U3.8 (PB1)
CAPSLOCK: J1.25, J12.25, U2.9
CAPSOUT: U2.6, U3.4 (PA6)
DRIVE+: J4.1, J4.2, R2.1
EXOUT: U2.12, U3.2 (PA4)
GND: C1.2, C2.2, C3.2, C5.2, C6.2, C7.2, D1.1 (K), D2.1 (K), J1.1, J3.1, J5.2, J6.2, J7.1, J9.1, J12.1, SW35.1, SW37.1, SW97.1, SW100.1, U1.7 (V_{SS}), U2.4, U2.7 (V_{SS}), U2.8, U3.14 (GND)
K1: JP1.2 (C), SW64.1
KK1: JP1.3 (B), U1.5, U1.6
KK2: SW67.1, U1.12
unnamed: D1.2 (A), R1.2
unnamed: D2.2 (A), R2.2
unnamed: D3.2 (A), RN2.2 (R1)
unnamed: D3.1 (K), U3.11 (PA1)
unnamed: D4.2 (A), RN2.3 (R2)
unnamed: D4.1 (K), U3.12 (PA2)
unnamed: D5.2 (A), RN2.4 (R3)
unnamed: D5.1 (K), U3.13 (PA3)
R0: J1.12, J3.13, J7.13, J9.12, J12.12, SW6.1, SW8.1, SW10.1, SW12.1, SW14.1, SW16.1, SW18.1, SW20.1, SW78.1, SW80.1, SW81.1, SW83.1, SW86.1, SW88.1, SW94.1, SW96.1, SW98.1
R1: J1.11, J9.11, J12.11, SW5.1, SW23.1, SW25.1, SW27.1, SW29.1, SW31.1, SW33.1, SW50.1, SW89.1
R2: J1.10, J9.10, J12.10, SW21.1, SW38.1, SW40.1, SW42.1, SW44.1, SW46.1, SW48.1, SW65.1, SW69.1, U1.11
R3: J1.9, J3.12, J7.12, J9.9, J12.9, JP1.1 (A), SW36.1, SW52.1, SW54.1, SW56.1, SW58.1, SW60.1, SW62.1, SW68.1, SW101.1, U1.8, U2.1
R4: J1.8, J2.1, J3.11, J7.11, J9.8, J12.8, SW1.1, SW53.1, SW55.1, SW57.1, SW59.1, SW61.1, SW63.1, SW66.1, SW70.1, SW74.1, SW91.1, SW92.1, SW93.1, SW103.1, SW106.1, U1.1, U1.4
R5: J1.7, J2.2, J3.10, J7.10, J9.7, J12.7, SW2.1, SW39.1, SW41.1, SW43.1, SW45.1, SW47.1, SW49.1, SW51.1, SW71.1, SW75.1, SW104.1, SW107.1
R6: J1.6, J2.3, J3.9, J7.9, J9.6, J12.6, SW3.1, SW22.1, SW24.1, SW26.1, SW28.1, SW30.1, SW32.1, SW34.1, SW72.1, SW76.1, SW105.1, SW108.1
R7: J1.5, J2.4, J3.8, J7.8, J9.5, J12.5, SW4.1, SW7.1, SW9.1, SW11.1, SW13.1, SW15.1, SW17.1, SW19.1, SW73.1, SW77.1, SW79.1, SW82.1, SW84.1, SW85.1, SW87.1, SW90.1, SW95.1, SW99.1, SW102.1, SW109.1
RESTORE: J1.3, J9.3, J12.3, SW35.2
SLKEY: RN1.4 (R3), SW37.2, U3.9 (PB0)
SLOUT: U3.3 (PA5)
UPDI: J5.3, U3.10 (~RESET/PA0)

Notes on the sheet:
C128 Laptop OPTION:
SHIFT
DESCRIPTION
Legend:
Normal
SPACE
SPACEBAR Support
C64Dwi OPTION:
- Standard 6U SPACEBAR with stabilizer support. - OptionL 9U SPACEBAR using additional support keys. - SHIFTLOCK toggle circuit with LED support. - CAPSLOCK and 40/80 toggle with LED support. - Inverted-T using C65-style SHIFT control. - Power and Drive Activity LEDs.
Select: - Normal (1-2) - Inverted-T (2-3)
SX64/C128 LOCKING KEYS
C128:
BLOCK HEADERS
POWER TAP
(*)
SX-64 Keyboard thickness: - Bottom to Top of keycaps...: 19.0 mm - Bottom to Bottom of keycaps...: 9.0 mm - Keycap height (tallest).......: 10.0 mm - Top of Pcb to bottom of keycap: 4.8 mm - PCB+Sheild....................: 3.2 mm
C128 Cursor:
NOTES
The ATTINY gets input from the locking keys which put GND voltage to the pin. The ATTINY debounces the inputs and toggles the corresponding output to the 4066 chip which connects the keyboard lines.
INVERTED-T CURSOR
LIGHTS:
Locking
Multi-configurable MX Keyboard: - C128 Standard Layout - C128 Optional F-Keys replacing top Cursor. - C128 Optional Inverted-T Cursor. - C128 "Laptop" without Numeric Pad. - C128 numpad implemented as duplicate C64 keys. - SX-64 Standard Layout with DB25 plug. - SX-64 Optional Inverted-T Cursor for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
CSX-V1-R1
SX64 F-Keys
SX64/C64 DB25
C128 CAPS
Configurable
C128/C64 HEADER
Block header help to protect traces when pcv sections are detached.
C128SX MX KEYBOARD
REVISIONS
FEATURES
* Do not populate with Inverted-T cursor option.
This circut is taken from the C65 schematics. Two keys K1 and KK2 control 4 lines on the 4066 that simulate pressing the SHIFT and DOWN or RIGHT keys as the same time.
Updated: 2023-09-01
- Sent to JLC on 2023-09-01 * Extra fee for "too many slots" * Separator holes too big. Must reduce to 1.8mm
C64 PINS
C128 PINS
NOTES: The ROW and COL designations are based on the original VIC-20 keyboard pinout, which is a variation of the PET pinout. The SX64/C64 DB25 does not connect LED, SHIFTLOCK, or extra GND pins. SHIFTLOCK is handled by onboard circuitry, and requires +5V to be present on pin 4.

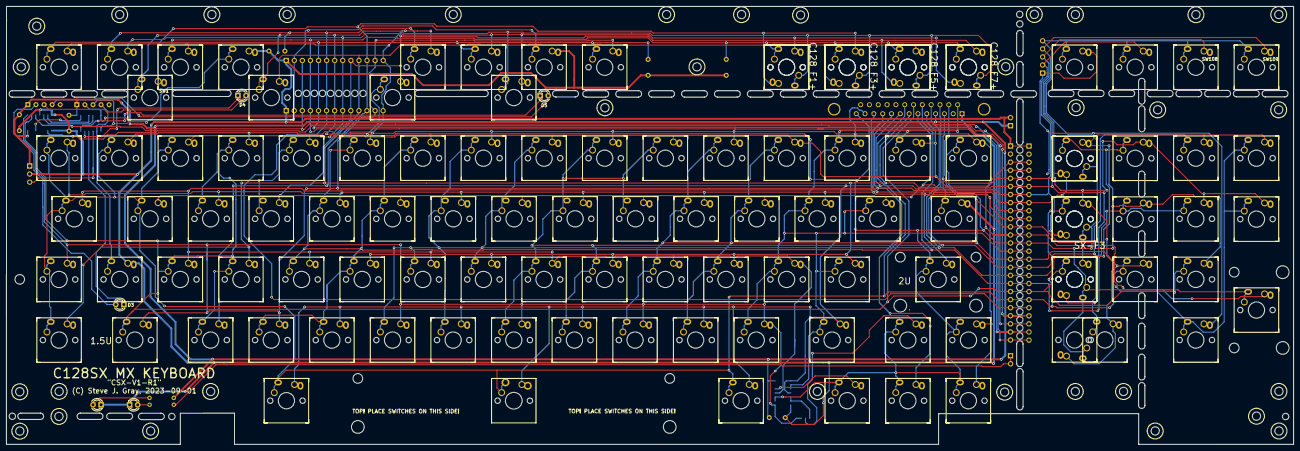
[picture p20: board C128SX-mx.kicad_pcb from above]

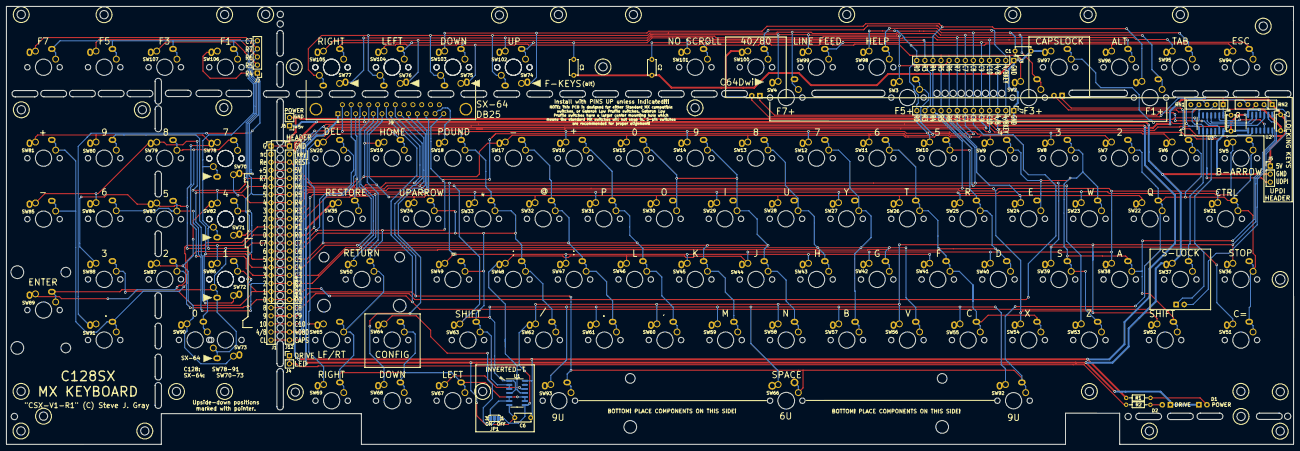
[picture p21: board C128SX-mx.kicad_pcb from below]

Board: 2 copper layers, 404.4 x 137.6 mm, 137 parts (23 on the bottom side), 43 nets.

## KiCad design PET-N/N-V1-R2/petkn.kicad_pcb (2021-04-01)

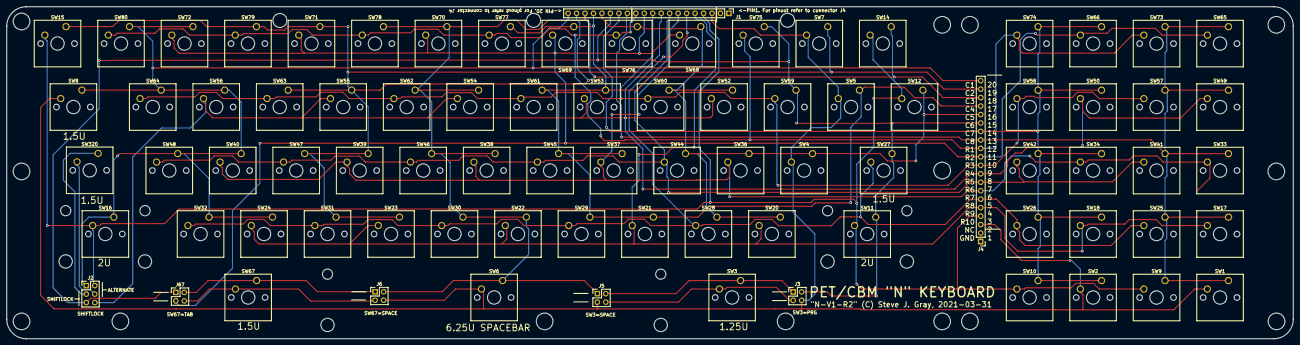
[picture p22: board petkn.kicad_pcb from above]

Board: 2 copper layers, 386.1 x 99.6 mm, 83 parts (0 on the bottom side), 24 nets.

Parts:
J1, J4: Conn_01x20; PinHeader_1x20_P2.54mm_Vertical
J2: Conn_02x03_Odd_Even; PinHeader_2x03_P2.54mm_Vertical
J3: LINK3; PinHeader_2x02_P2.54mm_Vertical
J5: SPACE1; PinHeader_2x02_P2.54mm_Vertical
J6: SPACE2; PinHeader_2x02_P2.54mm_Vertical
J67: LINK67; PinHeader_2x02_P2.54mm_Vertical
SW1: KP "="; SW_Cherry_MX_1.00u_PCB
SW2: KP "."; SW_Cherry_MX_1.00u_PCB
SW3: NC ($10); SW_Cherry_MX1A_1.25u_PCB
SW4: STOP; SW_Cherry_MX_1.00u_PCB
SW5: "<"; SW_Cherry_MX_1.00u_PCB
SW6: SPACE; SW_Cherry_MX1A_6.25u_PCB
SW7: "["; SW_Cherry_MX_1.00u_PCB
SW8: OFF/RVS; SW_Cherry_MX1A_1.50u_PCB
SW9: KP "-"; SW_Cherry_MX_1.00u_PCB
SW10: KP "0"; SW_Cherry_MX_1.00u_PCB
SW11: R SHIFT; SW_Cherry_MX_2.00u_PCB
SW12: ">"; SW_Cherry_MX_1.00u_PCB
SW14: "]"; SW_Cherry_MX_1.00u_PCB
SW15: "@"; SW_Cherry_MX_1.00u_PCB
SW16: L SHIFT; SW_Cherry_MX_2.00u_PCB
SW17: KP "+"; SW_Cherry_MX_1.00u_PCB
SW18: KP "2"; SW_Cherry_MX_1.00u_PCB
SW20: "?"; SW_Cherry_MX_1.00u_PCB
SW21: ","; SW_Cherry_MX_1.00u_PCB
SW22: "N"; SW_Cherry_MX_1.00u_PCB
SW23: "V"; SW_Cherry_MX_1.00u_PCB
SW24: "X"; SW_Cherry_MX_1.00u_PCB
SW25: KP "3"; SW_Cherry_MX_1.00u_PCB
SW26: KP "1"; SW_Cherry_MX_1.00u_PCB
SW27: RETURN; SW_Cherry_MX1A_1.50u_PCB
SW28: ";"; SW_Cherry_MX_1.00u_PCB
SW29: "M"; SW_Cherry_MX_1.00u_PCB
SW30: "B"; SW_Cherry_MX_1.00u_PCB
SW31: "C"; SW_Cherry_MX_1.00u_PCB
SW32: "Z"; SW_Cherry_MX_1.00u_PCB
SW33: KP "*"; SW_Cherry_MX_1.00u_PCB
SW34: KP "5"; SW_Cherry_MX_1.00u_PCB
SW36: ":"; SW_Cherry_MX_1.00u_PCB
SW37: "K"; SW_Cherry_MX_1.00u_PCB
SW38: "H"; SW_Cherry_MX_1.00u_PCB
SW39: "F"; SW_Cherry_MX_1.00u_PCB
SW40: "S"; SW_Cherry_MX_1.00u_PCB
SW41: KP "6"; SW_Cherry_MX_1.00u_PCB
SW42: KP "4"; SW_Cherry_MX_1.00u_PCB
SW44: "L"; SW_Cherry_MX_1.00u_PCB
SW45: "J"; SW_Cherry_MX_1.00u_PCB
SW46: "G"; SW_Cherry_MX_1.00u_PCB
SW47: "D"; SW_Cherry_MX_1.00u_PCB
SW48: "A"; SW_Cherry_MX_1.00u_PCB
SW49: KP "/"; SW_Cherry_MX_1.00u_PCB
SW50: KP "8"; SW_Cherry_MX_1.00u_PCB
SW52: "P"; SW_Cherry_MX_1.00u_PCB
SW53: "I"; SW_Cherry_MX_1.00u_PCB
SW54: "Y"; SW_Cherry_MX_1.00u_PCB
SW55: "R"; SW_Cherry_MX_1.00u_PCB
SW56: "W"; SW_Cherry_MX_1.00u_PCB
SW57: KP "9"; SW_Cherry_MX_1.00u_PCB
SW58: KP "7"; SW_Cherry_MX_1.00u_PCB
SW59: U ARROW; SW_Cherry_MX_1.00u_PCB
SW60: "O"; SW_Cherry_MX_1.00u_PCB
SW61: "U"; SW_Cherry_MX_1.00u_PCB
SW62: "T"; SW_Cherry_MX_1.00u_PCB
SW63: "E"; SW_Cherry_MX_1.00u_PCB
SW64: "Q"; SW_Cherry_MX_1.00u_PCB
SW65: INS/DEL; SW_Cherry_MX_1.00u_PCB
SW66: UP/DOWN; SW_Cherry_MX_1.00u_PCB
SW67: NC ($0A); SW_Cherry_MX_1.50u_PCB
SW68: ")"; SW_Cherry_MX_1.00u_PCB
SW69: "\"; SW_Cherry_MX_1.00u_PCB
SW70: "'"; SW_Cherry_MX_1.00u_PCB
SW71: "$"; SW_Cherry_MX_1.00u_PCB
SW72: QUOTE; SW_Cherry_MX_1.00u_PCB
SW73: LEFT/RIGHT; SW_Cherry_MX_1.00u_PCB
SW74: CLR/HOME; SW_Cherry_MX_1.00u_PCB
SW75: B ARROW; SW_Cherry_MX_1.00u_PCB
SW76: "("; SW_Cherry_MX_1.00u_PCB
SW77: "&"; SW_Cherry_MX_1.00u_PCB
SW78: "%"; SW_Cherry_MX_1.00u_PCB
SW79: "#"; SW_Cherry_MX_1.00u_PCB
SW80: "!"; SW_Cherry_MX_1.00u_PCB
SW320: S LOCK; SW_Cherry_MX1A_1.50u_PCB

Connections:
C1: J1.20, J2.1, J4.20, SW8.1, SW16.1, SW24.1, SW32.1, SW40.1, SW48.1, SW56.1, SW64.1, SW72.1, SW80.1
C2: J1.19, J4.19, SW7.1, SW15.1, SW23.1, SW31.1, SW39.1, SW47.1, SW55.1, SW63.1, SW71.1, SW79.1
C3: J1.18, J4.18, J5.1, J6.2, SW6.1, SW14.1, SW22.1, SW30.1, SW38.1, SW46.1, SW54.1, SW62.1, SW70.1, SW78.1
C4: J1.17, J4.17, SW5.1, SW21.1, SW29.1, SW37.1, SW45.1, SW53.1, SW61.1, SW69.1, SW77.1
C5: J1.16, J4.16, SW4.1, SW12.1, SW20.1, SW28.1, SW36.1, SW44.1, SW52.1, SW60.1, SW68.1, SW76.1
C6: J1.15, J2.5, J3.2, J4.15, J67.1, SW11.1, SW27.1, SW59.1, SW75.1
C7: J1.14, J4.14, SW2.1, SW10.1, SW18.1, SW26.1, SW34.1, SW42.1, SW50.1, SW58.1, SW66.1, SW74.1
C8: J1.13, J4.13, SW1.1, SW9.1, SW17.1, SW25.1, SW33.1, SW41.1, SW49.1, SW57.1, SW65.1, SW73.1
R1: J1.12, J4.12, SW73.2, SW74.2, SW75.2, SW76.2, SW77.2, SW78.2, SW79.2, SW80.2
R2: J1.11, J4.11, J67.3, SW65.2, SW66.2, SW68.2, SW69.2, SW70.2, SW71.2, SW72.2
R3: J1.10, J4.10, SW57.2, SW58.2, SW59.2, SW60.2, SW61.2, SW62.2, SW63.2, SW64.2
R4: J1.9, J2.6, J4.9, SW49.2, SW50.2, SW52.2, SW53.2, SW54.2, SW55.2, SW56.2
R5: J1.8, J4.8, SW41.2, SW42.2, SW44.2, SW45.2, SW46.2, SW47.2, SW48.2
R6: J1.7, J4.7, SW33.2, SW34.2, SW36.2, SW37.2, SW38.2, SW39.2, SW40.2
R7: J1.6, J4.6, SW25.2, SW26.2, SW27.2, SW28.2, SW29.2, SW30.2, SW31.2, SW32.2
R8: J1.5, J4.5, SW17.2, SW18.2, SW20.2, SW21.2, SW22.2, SW23.2, SW24.2
R9: J1.4, J2.2, J4.4, SW9.2, SW10.2, SW11.2, SW12.2, SW14.2, SW15.2, SW16.2
R10: J1.3, J3.4, J4.3, J5.3, J6.4, SW1.2, SW2.2, SW4.2, SW5.2, SW6.2, SW7.2, SW8.2
XC1: J2.3, SW320.1
XC3: J3.1, J5.2, SW3.1
XC67: J6.1, J67.2, SW67.1
XR1: J2.4, SW320.2
XR3: J3.3, J5.4, SW3.2
XR67: J6.3, J67.4, SW67.2

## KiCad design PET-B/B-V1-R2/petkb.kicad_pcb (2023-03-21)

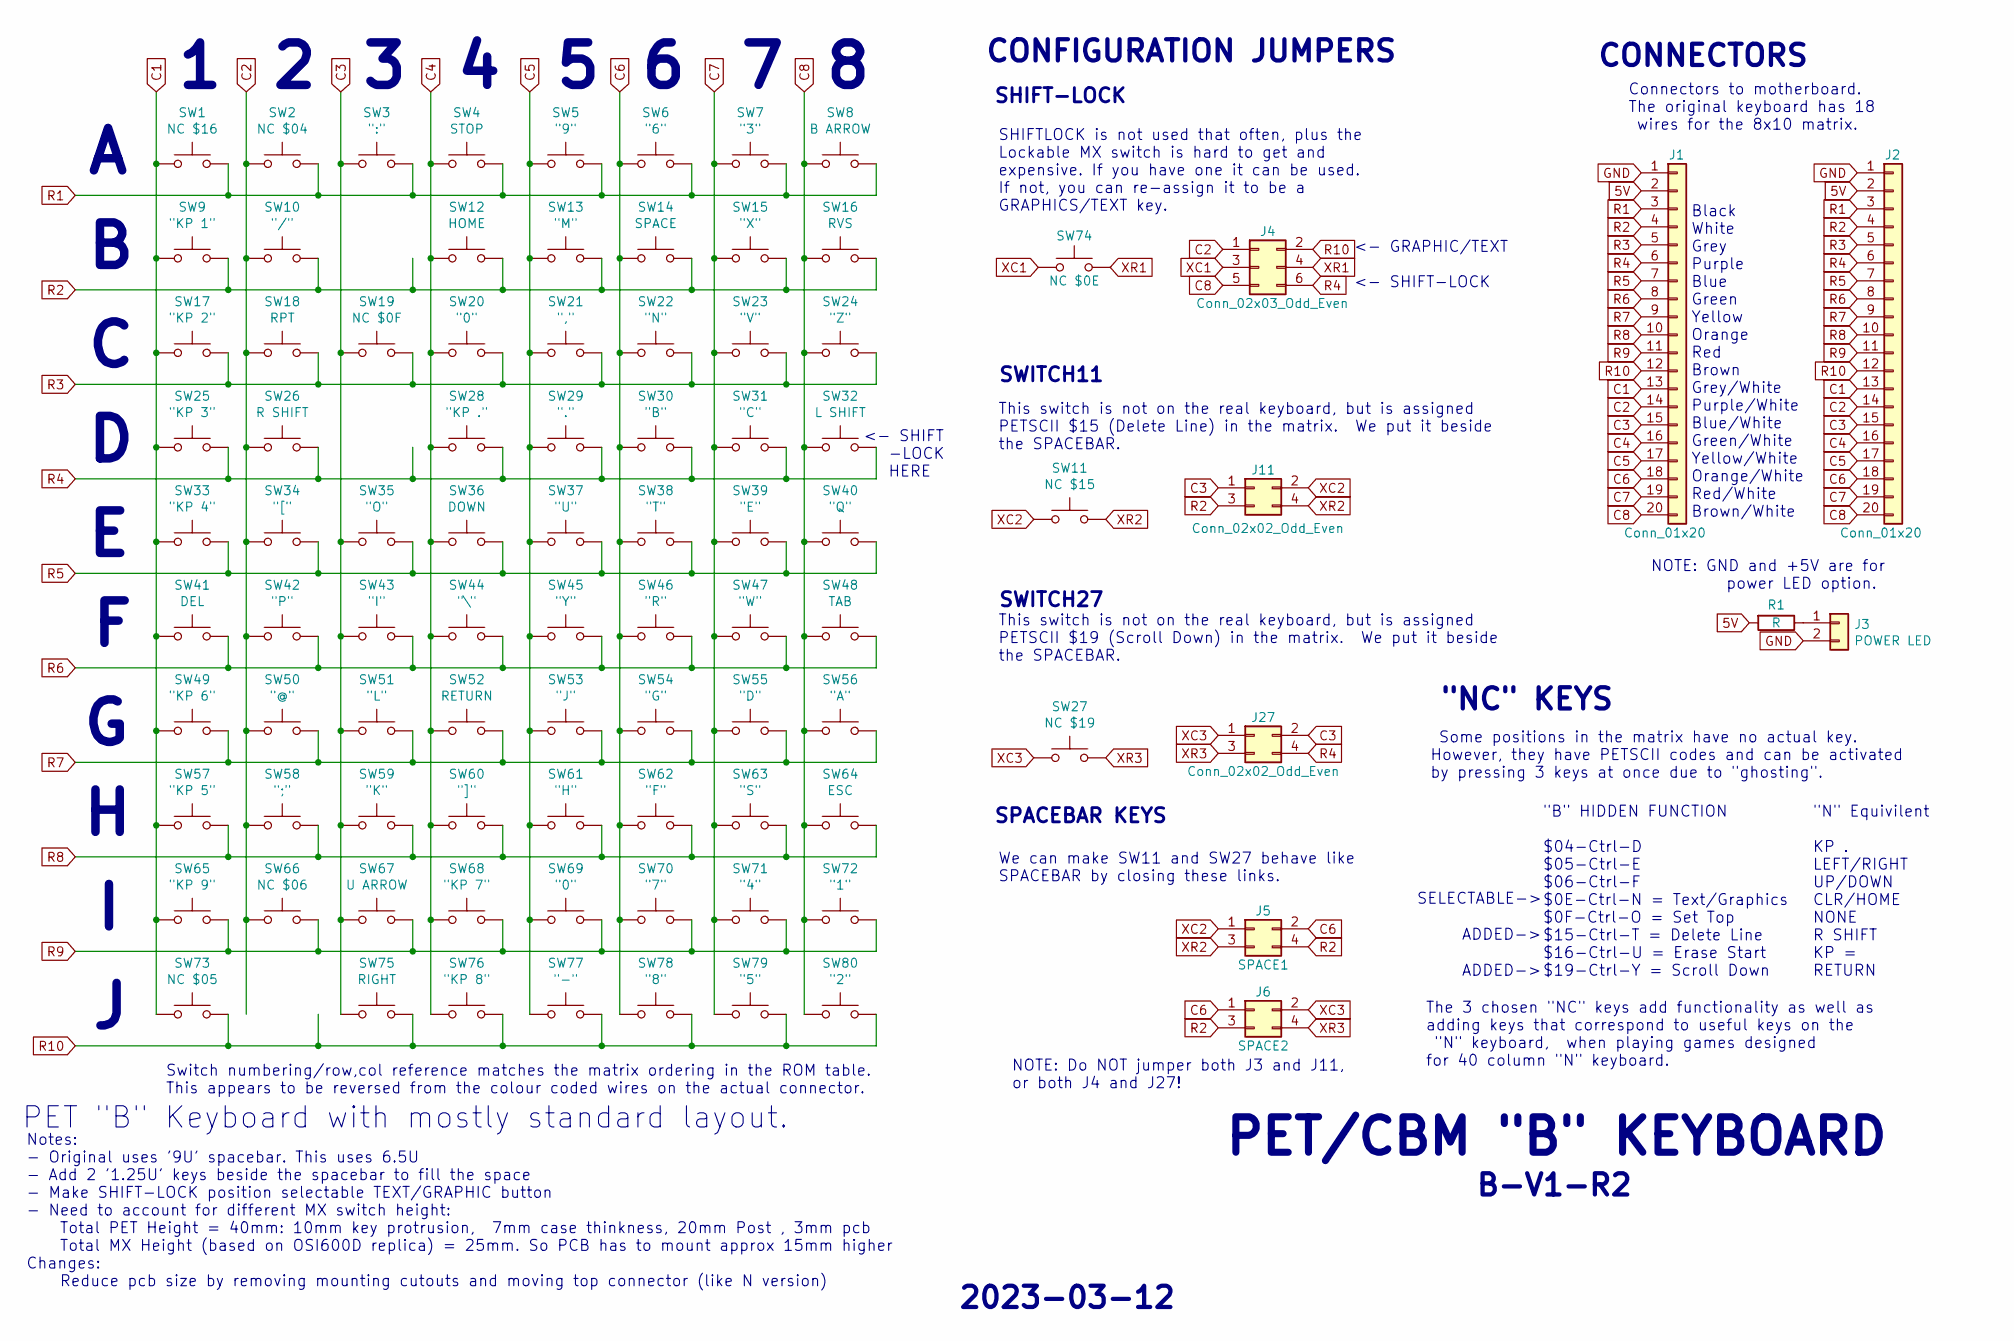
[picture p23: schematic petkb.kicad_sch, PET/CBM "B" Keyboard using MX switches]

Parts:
J1, J2: Conn_01x20; PinHeader_1x20_P2.54mm_Vertical
J3: POWER LED; PinHeader_1x02_P2.54mm_Vertical
J4: Conn_02x03_Odd_Even; PinHeader_2x03_P2.54mm_Vertical
J5: SPACE1; PinHeader_2x02_P2.54mm_Vertical
J6: SPACE2; PinHeader_2x02_P2.54mm_Vertical
J11, J27: Conn_02x02_Odd_Even; PinHeader_2x02_P2.54mm_Vertical
R1: R; R_Axial_DIN0207_L6.3mm_D2.5mm_P10.16mm_Horizontal
SW1: NC $16; SW_Cherry_MX_1.00u_PCB
SW2: NC $04; SW_Cherry_MX_1.00u_PCB
SW3: ":"; SW_Cherry_MX_1.00u_PCB
SW4: STOP; SW_Cherry_MX_1.00u_PCB
SW5: "9"; SW_Cherry_MX_1.00u_PCB
SW6: "6"; SW_Cherry_MX_1.00u_PCB
SW7: "3"; SW_Cherry_MX_1.00u_PCB
SW8: B ARROW; SW_Cherry_MX_1.00u_PCB
SW9: "KP 1"; SW_Cherry_MX_1.00u_PCB
SW10: "/"; SW_Cherry_MX_1.00u_PCB
SW11: NC $15; SW_Cherry_MX_1.50u_PCB
SW12: HOME; SW_Cherry_MX_1.00u_PCB
SW13: "M"; SW_Cherry_MX_1.00u_PCB
SW14: SPACE; SW_Cherry_MX_6.25u_PCB
SW15: "X"; SW_Cherry_MX_1.00u_PCB
SW16: RVS; SW_Cherry_MX_1.00u_PCB
SW17: "KP 2"; SW_Cherry_MX_1.00u_PCB
SW18: RPT; SW_Cherry_MX_1.00u_PCB
SW19: NC $0F; SW_Cherry_MX_1.25u_PCB
SW20: "0"; SW_Cherry_MX_2.00u_PCB
SW21: ","; SW_Cherry_MX_1.00u_PCB
SW22: "N"; SW_Cherry_MX_1.00u_PCB
SW23: "V"; SW_Cherry_MX_1.00u_PCB
SW24: "Z"; SW_Cherry_MX_1.00u_PCB
SW25: "KP 3"; SW_Cherry_MX_1.00u_PCB
SW26: R SHIFT; SW_Cherry_MX_1.50u_PCB
SW27: NC $19; SW_Cherry_MX_1.25u_PCB
SW28: "KP ."; SW_Cherry_MX_1.00u_PCB
SW29: "."; SW_Cherry_MX_1.00u_PCB
SW30: "B"; SW_Cherry_MX_1.00u_PCB
SW31: "C"; SW_Cherry_MX_1.00u_PCB
SW32: L SHIFT; SW_Cherry_MX_1.50u_PCB
SW33: "KP 4"; SW_Cherry_MX_1.00u_PCB
SW34: "["; SW_Cherry_MX_1.00u_PCB
SW35: "O"; SW_Cherry_MX_1.00u_PCB
SW36: DOWN; SW_Cherry_MX_1.00u_PCB
SW37: "U"; SW_Cherry_MX_1.00u_PCB
SW38: "T"; SW_Cherry_MX_1.00u_PCB
SW39: "E"; SW_Cherry_MX_1.00u_PCB
SW40: "Q"; SW_Cherry_MX_1.00u_PCB
SW41: DEL; SW_Cherry_MX_1.00u_PCB
SW42: "P"; SW_Cherry_MX_1.00u_PCB
SW43: "I"; SW_Cherry_MX_1.00u_PCB
SW44: "\"; SW_Cherry_MX_1.00u_PCB
SW45: "Y"; SW_Cherry_MX_1.00u_PCB
SW46: "R"; SW_Cherry_MX_1.00u_PCB
SW47: "W"; SW_Cherry_MX_1.00u_PCB
SW48: TAB; SW_Cherry_MX_1.50u_PCB
SW49: "KP 6"; SW_Cherry_MX_1.00u_PCB
SW50: "@"; SW_Cherry_MX_1.00u_PCB
SW51: "L"; SW_Cherry_MX_1.00u_PCB
SW52: RETURN; SW_Cherry_MX_2.00u_PCB
SW53: "J"; SW_Cherry_MX_1.00u_PCB
SW54: "G"; SW_Cherry_MX_1.00u_PCB
SW55: "D"; SW_Cherry_MX_1.00u_PCB
SW56: "A"; SW_Cherry_MX_1.00u_PCB
SW57: "KP 5"; SW_Cherry_MX_1.00u_PCB
SW58: ";"; SW_Cherry_MX_1.00u_PCB
SW59: "K"; SW_Cherry_MX_1.00u_PCB
SW60: "]"; SW_Cherry_MX_1.00u_PCB
SW61: "H"; SW_Cherry_MX_1.00u_PCB
SW62: "F"; SW_Cherry_MX_1.00u_PCB
SW63: "S"; SW_Cherry_MX_1.00u_PCB
SW64: ESC; SW_Cherry_MX_1.00u_PCB
SW65: "KP 9"; SW_Cherry_MX_1.00u_PCB
SW66: NC $06; SW_Cherry_MX_1.00u_PCB
SW67: U ARROW; SW_Cherry_MX_1.00u_PCB
SW68: "KP 7"; SW_Cherry_MX_1.00u_PCB
SW69: "0"; SW_Cherry_MX_1.00u_PCB
SW70: "7"; SW_Cherry_MX_1.00u_PCB
SW71: "4"; SW_Cherry_MX_1.00u_PCB
SW72: "1"; SW_Cherry_MX_1.00u_PCB
SW73: NC $05; SW_Cherry_MX_1.00u_PCB
SW74: NC $0E; SW_Cherry_MX_1.00u_PCB
SW75: RIGHT; SW_Cherry_MX_1.00u_PCB
SW76: "KP 8"; SW_Cherry_MX_1.00u_PCB
SW77: "-"; SW_Cherry_MX_1.00u_PCB
SW78: "8"; SW_Cherry_MX_1.00u_PCB
SW79: "5"; SW_Cherry_MX_1.00u_PCB
SW80: "2"; SW_Cherry_MX_1.00u_PCB

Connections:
5V: J1.2, J2.2, R1.2
C1: J1.13, J2.13, SW1.1, SW9.1, SW17.1, SW25.1, SW33.1, SW41.1, SW49.1, SW57.1, SW65.1, SW73.1
C2: J1.14, J2.14, J4.1, SW2.1, SW10.1, SW18.1, SW26.1, SW34.1, SW42.1, SW50.1, SW58.1, SW66.1
C3: J1.15, J2.15, J11.1, J27.2, SW3.1, SW19.1, SW35.1, SW43.1, SW51.1, SW59.1, SW67.1, SW75.1
C4: J1.16, J2.16, SW4.1, SW12.1, SW20.1, SW28.1, SW36.1, SW44.1, SW52.1, SW60.1, SW68.1, SW76.1
C5: J1.17, J2.17, SW5.1, SW13.1, SW21.1, SW29.1, SW37.1, SW45.1, SW53.1, SW61.1, SW69.1, SW77.1
C6: J1.18, J2.18, J5.2, J6.1, SW6.1, SW14.1, SW22.1, SW30.1, SW38.1, SW46.1, SW54.1, SW62.1, SW70.1, SW78.1
C7: J1.19, J2.19, SW7.1, SW15.1, SW23.1, SW31.1, SW39.1, SW47.1, SW55.1, SW63.1, SW71.1, SW79.1
C8: J1.20, J2.20, J4.5, SW8.1, SW16.1, SW24.1, SW32.1, SW40.1, SW48.1, SW56.1, SW64.1, SW72.1, SW80.1
GND: J1.1, J2.1, J3.2
unnamed: J3.1, R1.1
R1: J1.3, J2.3, SW1.2, SW2.2, SW3.2, SW4.2, SW5.2, SW6.2, SW7.2, SW8.2
R2: J1.4, J2.4, J5.4, J6.3, J11.3, SW9.2, SW10.2, SW12.2, SW13.2, SW14.2, SW15.2, SW16.2
R3: J1.5, J2.5, SW17.2, SW18.2, SW19.2, SW20.2, SW21.2, SW22.2, SW23.2, SW24.2
R4: J1.6, J2.6, J4.6, J27.4, SW25.2, SW26.2, SW28.2, SW29.2, SW30.2, SW31.2, SW32.2
R5: J1.7, J2.7, SW33.2, SW34.2, SW35.2, SW36.2, SW37.2, SW38.2, SW39.2, SW40.2
R6: J1.8, J2.8, SW41.2, SW42.2, SW43.2, SW44.2, SW45.2, SW46.2, SW47.2, SW48.2
R7: J1.9, J2.9, SW49.2, SW50.2, SW51.2, SW52.2, SW53.2, SW54.2, SW55.2, SW56.2
R8: J1.10, J2.10, SW57.2, SW58.2, SW59.2, SW60.2, SW61.2, SW62.2, SW63.2, SW64.2
R9: J1.11, J2.11, SW65.2, SW66.2, SW67.2, SW68.2, SW69.2, SW70.2, SW71.2, SW72.2
R10: J1.12, J2.12, J4.2, SW73.2, SW75.2, SW76.2, SW77.2, SW78.2, SW79.2, SW80.2
XC1: J4.3, SW74.1
XC2: J5.1, J11.2, SW11.1
XC3: J6.2, J27.1, SW27.1
XR1: J4.4, SW74.2
XR2: J5.3, J11.4, SW11.2
XR3: J6.4, J27.3, SW27.2

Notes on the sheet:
B-V1-R2
PET "B" Keyboard with mostly standard layout.
Notes: - Original uses '9U' spacebar. This uses 6.5U - Add 2 '1.25U' keys beside the spacebar to fill the space - Make SHIFT-LOCK position selectable TEXT/GRAPHIC button - Need to account for different MX switch height: Total PET Height = 40mm: 10mm key protrusion, 7mm case thinkness, 20mm Post , 3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
"N" Equivilent KP . LEFT/RIGHT UP/DOWN CLR/HOME NONE R SHIFT KP = RETURN
CONFIGURATION JUMPERS
NOTE: GND and +5V are for power LED option.
CONNECTORS
Connectors to motherboard. The original keyboard has 18 wires for the 8x10 matrix.
This switch is not on the real keyboard, but is assigned PETSCII $19 (Scroll Down) in the matrix. We put it beside the SPACEBAR.
NOTE: Do NOT jumper both J3 and J11, or both J4 and J27!
SWITCH11
SELECTABLE->
"B" HIDDEN FUNCTION $04-Ctrl-D $05-Ctrl-E $06-Ctrl-F $0E-Ctrl-N = Text/Graphics $0F-Ctrl-O = Set Top $15-Ctrl-T = Delete Line $16-Ctrl-U = Erase Start $19-Ctrl-Y = Scroll Down
This switch is not on the real keyboard, but is assigned PETSCII $15 (Delete Line) in the matrix. We put it beside the SPACEBAR.
<- SHIFT -LOCK HERE
The 3 chosen "NC" keys add functionality as well as adding keys that correspond to useful keys on the "N" keyboard, when playing games designed for 40 column "N" keyboard.
ADDED->
PET/CBM "B" KEYBOARD
2023-03-12
We can make SW11 and SW27 behave like SPACEBAR by closing these links.
SWITCH27
"NC" KEYS
SHIFTLOCK is not used that often, plus the Lockable MX switch is hard to get and expensive. If you have one it can be used. If not, you can re-assign it to be a GRAPHICS/TEXT key.
<- GRAPHIC/TEXT <- SHIFT-LOCK
Switch numbering/row,col reference matches the matrix ordering in the ROM table. This appears to be reversed from the colour coded wires on the actual connector.
SHIFT-LOCK
Black White Grey Purple Blue Green Yellow Orange Red Brown Grey/White Purple/White Blue/White Green/White Yellow/White Orange/White Red/White Brown/White
Some positions in the matrix have no actual key. However, they have PETSCII codes and can be activated by pressing 3 keys at once due to "ghosting".
SPACEBAR KEYS

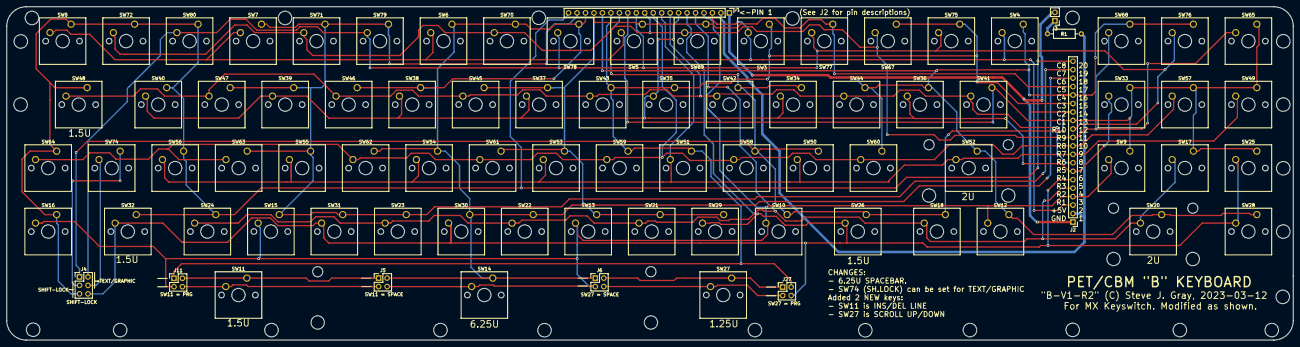
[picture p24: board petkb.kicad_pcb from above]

Board: 2 copper layers, 386.1 x 100.0 mm, 84 parts (0 on the bottom side), 27 nets.

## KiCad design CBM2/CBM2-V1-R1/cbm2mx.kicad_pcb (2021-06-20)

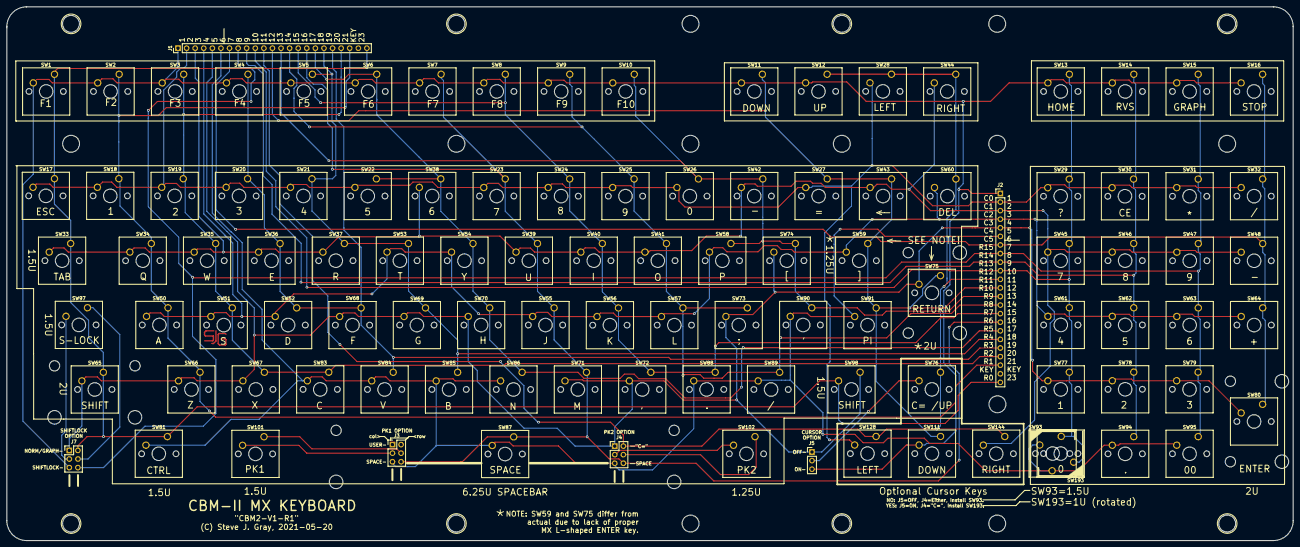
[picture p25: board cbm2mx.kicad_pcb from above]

Board: 2 copper layers, 380.5 x 157.9 mm, 106 parts (0 on the bottom side), 29 nets.

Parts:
J1, J2: Conn_01x23; PinHeader_1x23_P2.54mm_Vertical
J3: PK1; PinHeader_2x03_P2.54mm_Vertical
J4: PK2; PinHeader_2x03_P2.54mm_Vertical
J5: C=/UP; PinHeader_1x03_P2.54mm_Vertical
J7: S-LOCK OPT; PinHeader_2x03_P2.54mm_Vertical
SW1: "F1"; SW_Cherry_MX_1.00u_PCB
SW2: "F2"; SW_Cherry_MX_1.00u_PCB
SW3: "F3"; SW_Cherry_MX_1.00u_PCB
SW4: "F4"; SW_Cherry_MX_1.00u_PCB
SW5: "F5"; SW_Cherry_MX_1.00u_PCB
SW6: "F6"; SW_Cherry_MX_1.00u_PCB
SW7: "F7"; SW_Cherry_MX_1.00u_PCB
SW8: "F8"; SW_Cherry_MX_1.00u_PCB
SW9: "F9"; SW_Cherry_MX_1.00u_PCB
SW10: "F10"; SW_Cherry_MX_1.00u_PCB
SW11, SW111: "DOWN"; SW_Cherry_MX_1.00u_PCB
SW12: "UP"; SW_Cherry_MX_1.00u_PCB
SW13: "HOME"; SW_Cherry_MX_1.00u_PCB
SW14: "RVS"; SW_Cherry_MX_1.00u_PCB
SW15: "GRAPH"; SW_Cherry_MX_1.00u_PCB
SW16: "STOP"; SW_Cherry_MX_1.00u_PCB
SW17: "ESC"; SW_Cherry_MX_1.00u_PCB
SW18: "1"; SW_Cherry_MX_1.00u_PCB
SW19: "2"; SW_Cherry_MX_1.00u_PCB
SW20: "3"; SW_Cherry_MX_1.00u_PCB
SW21: "4"; SW_Cherry_MX_1.00u_PCB
SW22: "5"; SW_Cherry_MX_1.00u_PCB
SW23: "7"; SW_Cherry_MX_1.00u_PCB
SW24: "8"; SW_Cherry_MX_1.00u_PCB
SW25: "9"; SW_Cherry_MX_1.00u_PCB
SW26: "0"; SW_Cherry_MX_1.00u_PCB
SW27: "="; SW_Cherry_MX_1.00u_PCB
SW28, SW128: "LEFT"; SW_Cherry_MX_1.00u_PCB
SW29: KP "?"; SW_Cherry_MX_1.00u_PCB
SW30: KP "CE"; SW_Cherry_MX_1.00u_PCB
SW31: KP "*"; SW_Cherry_MX_1.00u_PCB
SW32: KP "/"; SW_Cherry_MX_1.00u_PCB
SW33: "TAB"; SW_Cherry_MX_1.50u_PCB
SW34: "Q"; SW_Cherry_MX_1.00u_PCB
SW35: "W"; SW_Cherry_MX_1.00u_PCB
SW36: "E"; SW_Cherry_MX_1.00u_PCB
SW37: "R"; SW_Cherry_MX_1.00u_PCB
SW38: "6"; SW_Cherry_MX_1.00u_PCB
SW39: "U"; SW_Cherry_MX_1.00u_PCB
SW40: "I"; SW_Cherry_MX_1.00u_PCB
SW41: "O"; SW_Cherry_MX_1.00u_PCB
SW42: "-"; SW_Cherry_MX_1.00u_PCB
SW43: "B-ARROW"; SW_Cherry_MX_1.00u_PCB
SW44, SW144: "RIGHT"; SW_Cherry_MX_1.00u_PCB
SW45: KP "7"; SW_Cherry_MX_1.00u_PCB
SW46: KP "8"; SW_Cherry_MX_1.00u_PCB
SW47: KP "9"; SW_Cherry_MX_1.00u_PCB
SW48: KP "-"; SW_Cherry_MX_1.00u_PCB
SW50: "A"; SW_Cherry_MX_1.00u_PCB
SW51: "S"; SW_Cherry_MX_1.00u_PCB
SW52: "D"; SW_Cherry_MX_1.00u_PCB
SW53: "T"; SW_Cherry_MX_1.00u_PCB
SW54: "Y"; SW_Cherry_MX_1.00u_PCB
SW55: "J"; SW_Cherry_MX_1.00u_PCB
SW56: "K"; SW_Cherry_MX_1.00u_PCB
SW57: "L"; SW_Cherry_MX_1.00u_PCB
SW58: "P"; SW_Cherry_MX_1.00u_PCB
SW59: "]"; SW_Cherry_MX_1.25u_PCB
SW60: "DEL"; SW_Cherry_MX_1.00u_PCB
SW61: KP "4"; SW_Cherry_MX_1.00u_PCB
SW62: KP "5"; SW_Cherry_MX_1.00u_PCB
SW63: KP "6"; SW_Cherry_MX_1.00u_PCB
SW64: KP "+"; SW_Cherry_MX_1.00u_PCB
SW65: "SHIFT"; SW_Cherry_MX_2.00u_PCB
SW66: "Z"; SW_Cherry_MX_1.00u_PCB
SW67: "X"; SW_Cherry_MX_1.00u_PCB
SW68: "F"; SW_Cherry_MX_1.00u_PCB
SW69: "G"; SW_Cherry_MX_1.00u_PCB
SW70: "H"; SW_Cherry_MX_1.00u_PCB
SW71: "M"; SW_Cherry_MX_1.00u_PCB
SW72: ","; SW_Cherry_MX_1.00u_PCB
SW73: ";"; SW_Cherry_MX_1.00u_PCB
SW74: "["; SW_Cherry_MX_1.00u_PCB
SW75: "RETURN"; SW_Cherry_MX_2.00u_Vertical_PCB
SW76: "C="/"UP"; SW_Cherry_MX_1.00u_PCB
SW77: KP "1"; SW_Cherry_MX_1.00u_PCB
SW78: KP "2"; SW_Cherry_MX_1.00u_PCB
SW79: KP "3"; SW_Cherry_MX_1.00u_PCB
SW80: "ENTER"; SW_Cherry_MX_2.00u_Vertical_PCB
SW81: "CTRL"; SW_Cherry_MX_1.50u_PCB
SW83: "C"; SW_Cherry_MX_1.00u_PCB
SW84: "V"; SW_Cherry_MX_1.00u_PCB
SW85: "B"; SW_Cherry_MX_1.00u_PCB
SW86: "N"; SW_Cherry_MX_1.00u_PCB
SW87: "SPACE"; SW_Cherry_MX_6.25u_PCB
SW88: "."; SW_Cherry_MX_1.00u_PCB
SW89: "/"; SW_Cherry_MX_1.00u_PCB
SW90: "'"; SW_Cherry_MX_1.00u_PCB
SW91: "PI"; SW_Cherry_MX_1.00u_PCB
SW93: KP"0" Reg; SW_Cherry_MX1A_1.25u_PCB
SW94: KP "."; SW_Cherry_MX_1.00u_PCB
SW95: KP "00"; SW_Cherry_MX_1.00u_PCB
SW97: S-LOCK; SW_Cherry_MX_1.50u_PCB
SW98: R-SHIFT; SW_Cherry_MX_1.50u_PCB
SW101: PRG1; SW_Cherry_MX1A_1.50u_PCB
SW102: PRG2; SW_Cherry_MX1A_1.25u_PCB
SW193: KP"0" Alternate; SW_Cherry_MX_1.00u_PCB

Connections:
C0: J1.1, J2.1, J5.3, J7.5, SW1.2, SW2.2, SW3.2, SW4.2, SW5.2, SW6.2, SW7.2, SW8.2, SW9.2, SW10.2, SW11.2, SW12.2, SW13.2, SW14.2, SW15.2, SW16.2, SW111.2
C1: J1.2, J2.2, SW17.2, SW18.2, SW19.2, SW20.2, SW21.2, SW22.2, SW23.2, SW24.2, SW25.2, SW26.2, SW27.2, SW28.2, SW29.2, SW30.2, SW31.2, SW32.2, SW128.2
C2: J1.3, J2.3, SW33.2, SW34.2, SW35.2, SW36.2, SW37.2, SW38.2, SW39.2, SW40.2, SW41.2, SW42.2, SW43.2, SW44.2, SW45.2, SW46.2, SW47.2, SW48.2, SW144.2
C3: J1.4, J2.4, SW50.2, SW51.2, SW52.2, SW53.2, SW54.2, SW55.2, SW56.2, SW57.2, SW58.2, SW59.2, SW60.2, SW61.2, SW62.2, SW63.2, SW64.2
C4: J1.5, J2.5, J4.1, J5.1, J7.1, SW65.2, SW66.2, SW67.2, SW68.2, SW69.2, SW70.2, SW71.2, SW72.2, SW73.2, SW74.2, SW75.2, SW77.2, SW78.2, SW79.2, SW80.2, SW98.1
C5: J1.6, J2.6, J3.5, J4.5, SW81.2, SW83.2, SW84.2, SW85.2, SW86.2, SW87.2, SW88.2, SW89.2, SW90.2, SW91.2, SW93.2, SW94.2, SW95.2, SW193.1
CEQC: J5.2, SW76.2
PK1C: J3.3, SW101.2
PK1R: J3.4, SW101.1
PK2C: J4.3, SW102.2
PK2R: J4.4, SW102.1
R0: J1.23, J2.23, J7.2, SW1.1, SW17.1, SW33.1, SW65.1, SW81.1, SW98.2
R1: J1.21, J2.21, SW2.1, SW18.1, SW34.1, SW50.1, SW66.1
R2: J1.20, J2.20, SW3.1, SW19.1, SW35.1, SW51.1, SW67.1, SW83.1
R3: J1.19, J2.19, SW4.1, SW20.1, SW36.1, SW52.1, SW68.1, SW84.1
R4: J1.18, J2.18, SW5.1, SW21.1, SW37.1, SW53.1, SW69.1, SW85.1
R5: J1.17, J2.17, SW6.1, SW22.1, SW38.1, SW54.1, SW70.1, SW86.1
R6: J1.16, J2.16, J3.6, J4.6, SW7.1, SW23.1, SW39.1, SW55.1, SW71.1, SW87.1
R7: J1.15, J2.15, SW8.1, SW24.1, SW40.1, SW56.1, SW72.1, SW88.1
R8: J1.14, J2.14, SW9.1, SW25.1, SW41.1, SW57.1, SW73.1, SW89.1
R9: J1.13, J2.13, SW10.1, SW26.1, SW42.1, SW58.1, SW74.1, SW90.1
R10: J1.12, J2.12, SW11.1, SW27.1, SW43.1, SW59.1, SW75.1, SW91.1, SW111.1
R11: J1.11, J2.11, J4.2, SW12.1, SW28.1, SW44.1, SW60.1, SW76.1, SW128.1, SW144.1
R12: J1.10, J2.10, SW13.1, SW29.1, SW45.1, SW61.1, SW77.1, SW93.1, SW193.2
R13: J1.9, J2.9, SW14.1, SW30.1, SW46.1, SW62.1, SW78.1, SW94.1
R14: J1.8, J2.8, J7.6, SW15.1, SW31.1, SW47.1, SW63.1, SW79.1, SW95.1
R15: J1.7, J2.7, SW16.1, SW32.1, SW48.1, SW64.1, SW80.1
SLOCKC: J7.3, SW97.2
SLOCKR: J7.4, SW97.1

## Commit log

2020-12-22 Initial Release
    B-V1-R1 complete
    N-V1-R1 pcb ordered
    [petkb.kicad_pcb, petkb.sch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]
2021-01-22 N-V1-R1 spacing fix.
    Gerber directory renamed. Do not use gerbers! Fix to PCB spacing.
    Should be ok, but no gerbers or pcb yet. use at own risk! Do not use the
    gerbers in the error directory unless you just need a keyboard and wont
    be installing it in a case!
    [petkn.kicad_pcb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]
2021-04-01 Release N-V1-R2
    Full Kicad files and Gerbers
    [petkn.kicad_pcb, petkn.sch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]
2021-04-01 Update N-V1-R2 schematic
    Updated schematic to remove unused switches, and replace with some more
    descriptive text to make alternate configurations clearer/
    [petkn.sch]
2021-06-20 CBM2-V1-R1
    Add CBM-II Keyboard, V1-R1. This design is complete,. The PCB mounts
    directly to the case and all keys are functional. It uses a 6.25U
    spacebar.
    [cbm2mx.kicad_pcb, cbm2mx.sch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]
2023-03-21 B-V1-R2 Release
    B-V1-R2 design complete and tested good. Includes Kicad 7 design files and gerbers. Boards were sent to JLCPCB.
    [petkb.kicad_pcb, petkb.kicad_sch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]
2024-02-25 Folder Re-Org
    Adding root folders for each machine, with subfolders for revisions.
    [cbm2mx.kicad_pcb, cbm2mx.sch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]
2024-02-26 Add C128SX - CSX-V1-R1
    This is the C128SX customizable keyboard. I have made boards and am currently testing various configurations and options. Check the README for more info.
    [C128SX-mx-B_Cu.gbr, C128SX-mx-B_Mask.gbr, C128SX-mx-B_Silkscreen.gbr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]
2024-02-26 V364 Released.
    Tested and working.
    [v364mx.kicad_pcb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]
2025-12-05 Add MX-Toggle V1
    MX-Toggle adds locking switch functionality to keyboards using regular MX switches. Usable for my earlier designs. Requires 5Vpower and modification to the PCB. All SMT components for a thin footprin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
    [mxtoggle-B_Cu.gbr, mxtoggle-B_Mask.gbr, mxtoggle-B_Silkscreen.gbr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]
2025-12-06 Updated resistor values, BOM
    LED's were too bright. Changed to 1K. Generated new interactive BOM. Add link to Mike's MX-Lock github.
